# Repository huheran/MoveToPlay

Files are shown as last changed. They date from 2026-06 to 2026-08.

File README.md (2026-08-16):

<p align="center">
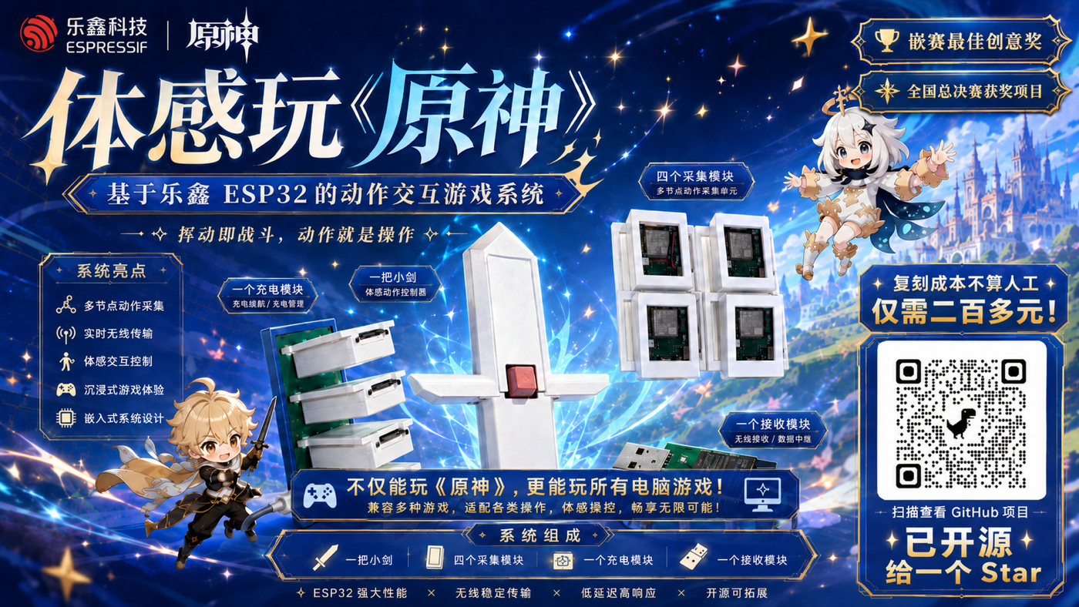
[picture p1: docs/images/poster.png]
MoveToPlay
  
</p>

# MoveToPlay

> 把身体变成手柄。

[English](README.en.md) · 简体中文


[]()
[]()
[]()

MoveToPlay 是一套基于 ESP32-S3 的开源体感外设。你在胸口、两只手、腿上各绑一个 Tracker，手里拿一把剑形的 Blade，插在电脑上的 Dongle 就能看懂你在跳、在挥剑、在奔跑，然后替你按下对应的按键。不用碰键盘和手柄，用身体直接打游戏。

## 目录

- [它能干什么](#它能干什么)
- [三个设备](#三个设备)
- [怎么玩](#怎么玩)
- [硬件](#硬件)
- [固件](#固件)
- [Windows Companion](#windows-companion)
- [训练自己的动作](#训练自己的动作)
- [云端训练服务](#云端训练服务)
- [目录结构](#目录结构)
- [许可证](#许可证)

## 它能干什么

对着屏幕挥一下剑，游戏里的角色就砍一刀；原地跳一下，角色就跳起来；迈步走路，角色就开始走。识别到的动作会变成真实的键盘、鼠标输入，所以理论上任何 PC 游戏都能用，只要把动作映射到对应的键。

默认键位是照着《原神》调的，开箱就能玩：

| 动作 | 默认输出 |
| --- | --- |
| 空闲 / 动作噪声 | 无 |
| 行走 | 按住 W |
| 奔跑 | 按住 Shift + W |
| 右手挥砍 | 鼠标左键连点 |
| 跳跃 | 空格 |
| 踢 | E |
| 左手抬起 | M |
| 右手抬起 | X |
| 双手交叉额头 | 角色键 1–4 循环 |
| 下压 | F |
| 射击 | 鼠标右键定时按住 |
| 左转 / 右转 | 视角左转 / 右转 |
| 奥特曼光线 | Q |

这套映射不是写死在固件里的。Dongle 有个 Wi-Fi 配置页，连上之后每个动作都能单独调输出、触发方式和阈值，改完保存在设备上，具体见[固件](#固件)。

## 三个设备

整套系统就三种硬件，各司其职：

- **Tracker × 4** —— 绑在胸口、右手、左手、腿上。里面是一颗 LSM6DSV 六轴 IMU，以 100 Hz 采样，通过 ESP-NOW 无线发给 Dongle。
- **Blade** —— 剑形控制器，一颗按键加一块 MAX30102 心率传感器。按住按键转动身体，胸口 Tracker 的陀螺仪就把转身和俯仰转成鼠标视角；采集数据时，这按键用来给动作打点。
- **Dongle** —— 插在电脑上的接收器。汇总所有节点的数据，在设备上跑随机森林识别动作，再伪装成 USB 键盘 + 鼠标输出。同时也是 USB 虚拟串口，供 Companion 读遥测、采数据、烧固件。

识别分两个随机森林：一个负责「持续状态」（空闲 / 走路 / 跑步 / 挥剑 / 动作噪声），50 棵树、5 个类别；另一个负责「瞬间动作」（跳、踢、抬手这些），180 棵树、15 个类别。特征都是 812 维，全部在 ESP32-S3 上本地跑，不依赖电脑端做任何识别。

## 怎么玩

最快的一条路：

1. **做硬件**。按下面的推荐组合打样 PCB、打印外壳、焊接。图纸在 `hardware/`。
2. **烧固件**。装好 ESP-IDF，把 6 个设备——1 个 Dongle、1 个 Blade、4 个 Tracker——依次编译烧录。
3. **绑上就玩**。Dongle 插电脑，Tracker 绑身上，开游戏。

只用官方公开的数据和模型的话，不用碰任何训练脚本。想用自己的动作重新训练，才需要 Python 和训练那套东西。

## 硬件

PCB 源工程和 3D 模型都在 `hardware/` 下，PCB 用的是嘉立创 EDA（`.eprj2`），外壳提供 SolidWorks / STEP / STL 三种格式。首次复刻推荐功能够用、结构最简单的 V1.0 组合：

- **Blade**：`Blade_V1.0_Nromal`（不带心率，文件名里的 `Nromal` 是早期拼写，保留原样）
- **Tracker**：手焊选 `Tracker_V1.0_Top-Battery`，贴片选 `Tracker_V1.0_Top-Battery_SMT`
- **Dongle**：`Dongle_SW1` / `Dongle_SW2` / `Dongle_SW3` 任选一个，只有按键不一样
- 充电底座，可选

这套组合不需要 `Blade_V2.0_HR(Heart Rate)` 和 `Heart_Rate_V2.0`。PCB 和外壳要按版本对应：V1.0 PCB 配 V1.0 模型，V2.0 配 V2.0，别混用。具体的工程清单、版本差异和对应关系见 [`hardware/pcb/README.md`](hardware/pcb/README.md) 和 [`hardware/3d-models/README.md`](hardware/3d-models/README.md)。

大文件走 Git LFS，克隆完先拉一下：

```bash
git lfs install
git lfs pull
```

投板前记得自己在嘉立创 EDA 里核对一遍 Gerber、钻孔、BOM、坐标和原理图，打印外壳前也核对尺寸和公差。

## 固件

固件工程在仓库根目录，ESP-IDF 5.5.x 就能编译：

```bash
idf.py build
idf.py -p <串口> flash monitor
```

三种设备共用同一份代码，靠 `main/app_main.c` 顶部的 `M2P_BOARD_PROFILE` 区分。改一次数字、烧一次：

| 值 | 设备 |
| --- | --- |
| `1` | Dongle |
| `2` | Blade |
| `3` | 胸口 Tracker |
| `4` | 右手 Tracker |
| `5` | 左手 Tracker |
| `6` | 腿部 Tracker |

```c
#define M2P_BOARD_PROFILE 1
```

推荐组合一共要烧 6 个设备，就是把上面这个数字从 1 到 6 各烧一遍。默认按 8 MB flash 构建（16 MB 的 Dongle 也能用），要显式指定的话：

```bash
# 8MB
idf.py -B build-tracker8mb \
  -D "SDKCONFIG=build-tracker8mb/sdkconfig" \
  -D "SDKCONFIG_DEFAULTS=sdkconfig.defaults.8mb" \
  build

# 16MB
idf.py -B build-dongle16mb \
  -D "SDKCONFIG=build-dongle16mb/sdkconfig" \
  -D "SDKCONFIG_DEFAULTS=sdkconfig.defaults.16mb" \
  build
```

Dongle 上长按按键 2 秒，会在三种运行状态之间循环，靠 LED 颜色区分：**绿 = 游戏**、**橙 = 采集**、**蓝 = Wi-Fi 维护**。进了蓝色状态后，手机或电脑连上 `MoveToPlay-Dongle` 这个热点（无密码），打开 `http://192.168.4.1/` 就能看设备状态、改动作映射。

配置页里每个动作可以设成：按一下键盘、按住键盘、角色键 1–4 循环、鼠标左键点击、鼠标右键定时按住、鼠标左键按住、鼠标左移 / 右移、视角左转 / 右转。触发方式有四种：冷却、刚出现、持续帧、重复。还能单独调每个动作的置信度阈值（30–95%）和冷却时间，配置存在设备 NVS 里，断电不丢。

## Windows Companion

Companion 是可选的 Windows 桌面端，面向买成品的人；自己复刻、只想体验体感控制的话可以不用装。它干这些事：

- 一个透明置顶、鼠标穿透的游戏悬浮层，显示当前动作、强度、心率、卡路里和连击
- 8 套主题：原神、鸣潮、我的世界、艾尔登法环、GTA V、赛博朋克 2077、通用、科幻竞技
- 动作事件标记、采集会话管理、上传训练、固件下载与回滚

需要 .NET 8 SDK 和 Windows 10/11：

```powershell
dotnet run --project companion/MoveToPlay.Companion/MoveToPlay.Companion.csproj
```

没有硬件时加 `--demo` 用模拟数据预览界面：

```powershell
dotnet run --project companion/MoveToPlay.Companion/MoveToPlay.Companion.csproj -- --demo
```

它会自动找 USB VID `303A`、PID `4005` 的 Dongle，设备插拔后自动重连。运行中 Dongle 每 100 ms 发一行 JSON 遥测——当前动作、置信度、强度、四个 Tracker 的在线和电量——Companion 拿来做悬浮层和统计。

点「结束运动并测量心率」会唤醒 Blade，用 MAX30102 测 10 秒心率；卡路里按动作 MET、强度和体重（默认 68 kg，`--weight` 可改）估算，不是医疗级数据。目前 Companion 只能烧 Dongle 固件，Blade 和 Tracker 还是得用 ESP-IDF 自己编译烧录。更多细节见 [`companion/MoveToPlay.Companion/README.md`](companion/MoveToPlay.Companion/README.md)。

## 训练自己的动作

想用自己的动作数据重新训练模型，流程是：采集 → 合并 → 训练 → 装进固件。用官方公开数据的话，跳过前两步，直接训练。

先准备环境。本地训练要 Python 3.11+，Windows 上一键搞定（第一次会建 `.venv-training` 并装好固定版本依赖）：

```powershell
# 先验证数据和环境
powershell -ExecutionPolicy Bypass -File training/run-local.ps1 -ValidateOnly -Reinstall
# 再训练
powershell -ExecutionPolicy Bypass -File training/run-local.ps1
```

也可以用 Docker，结果一致：

```powershell
docker build -f training/Dockerfile -t movetoplay-training:1 .
docker run --rm `
  --mount "type=bind,src=$PWD/data,dst=/workspace/data,readonly" `
  --mount "type=bind,src=$PWD/output,dst=/workspace/output" `
  movetoplay-training:1
```

每次训练都会生成一个独立目录，不会直接覆盖固件里的模型。训练通过质量门禁后，把产物装进固件、重新编译 Dongle：

```powershell
python tools/install_rf_model.py --run-dir output/training-runs/<run-id> --dry-run
python tools/install_rf_model.py --run-dir output/training-runs/<run-id>
idf.py -B build-dongle \
  -D "SDKCONFIG=build-dongle/sdkconfig" \
  -D "SDKCONFIG_DEFAULTS=sdkconfig.defaults.8mb" \
  build
```

**采集自己的数据**：用 Companion 采集，或者命令行：

```powershell
python -m pip install -r training/requirements-collection.txt
python tools/collect_imu_events.py --port COM6 --baud 115200 --output data/my-sessions/session_001.csv --autostart
```

**合并并生成 manifest**：

```powershell
python tools/prepare_rf_dataset.py --input-dir data/my-sessions --output-dir data/processed/my-dataset --dataset-id my-dataset
```

**训练自己的数据集**：

```powershell
powershell -ExecutionPolicy Bypass -File training/run-local.ps1 -DatasetManifest data/processed/my-dataset/dataset_manifest.json
```

数据格式很简单：samples 一行是 `pc_timestamp_ms,board_timestamp_ms,node_id,ax,ay,az,gx,gy,gz,state_label,session_id`，events 一行是 `event_id,event_group,event_type,pc_timestamp_ms,state_label,session_id`。`node_id` 固定 1=胸、2=右手、3=左手、4=腿，四个节点都得有数据。

公开数据由 Git LFS 管理，manifest 记录了大小、行数、标签分布和 SHA-256，训练前会逐项校验。两个模型都得过质量门禁才算通过：状态模型准确率 ≥ 0.98，事件模型准确率 ≥ 0.97、macro-F1 ≥ 0.96。还有个关键点：复现已部署模型必须用 `requirements.txt` 里固定的 scikit-learn 1.7.2，换个版本即使准确率一样，生成的数组内部结构也可能不同。完整的采集、合并、验证、Docker 复现和格式说明都在 [`training/README.md`](training/README.md)。

## 云端训练服务

不是复刻的必需步骤。`server/` 是一个 API + worker 分离的云端训练服务，共享 SQLite 状态库，负责数据校验、异步训练、质量门禁、固件编译和版本管理。API 只绑定 `127.0.0.1:8000`，走 SSH 隧道，业务接口要 Bearer Token。

人一多任务会排队，网络不稳也容易失败，所以现阶段建议本地训练。本地起一个做开发测试：

```powershell
python -m pip install -r server/requirements-dev.txt
Push-Location server
python -m pytest
Pop-Location
```

接口说明见 [`server/API_PROTOCOL.md`](server/API_PROTOCOL.md)，部署说明见 [`server/README.md`](server/README.md)。真实令牌、私钥、OSS 凭据都只放在服务器上，不要进 Git。

## 目录结构

```text
MoveToPlay/
├── main/             # ESP-IDF 固件（三种设备共用，generated/ 放模型 C 数组）
├── companion/        # Windows WPF 桌面端 + 冒烟测试
├── training/         # 训练流水线、Docker 环境和公开数据 manifest
├── data/             # Git LFS 管理的公开随机森林训练数据
├── server/           # 云端训练 API 与 worker
├── installer/        # Windows 安装包构建脚本（仅内部分发用）
├── hardware/
│   ├── pcb/          # 嘉立创 EDA PCB 源工程
│   └── 3d-models/    # SolidWorks / STEP / STL 结构模型
├── tools/            # 采集、分析、训练、导出脚本
├── analysis/         # 动作数据诊断脚本
├── partitions*.csv   # ESP32-S3 分区表
└── sdkconfig.defaults*   # ESP-IDF 默认配置
```

## 许可证

分目录授权：

- 软件、固件、训练工具、服务端和文档：Apache License 2.0（[`LICENSE`](LICENSE)、[`NOTICE`](NOTICE)）
- PCB 设计：CERN Open Hardware Licence v2 – Permissive（[`hardware/pcb/LICENSE`](hardware/pcb/LICENSE)）
- 3D 模型：CC0 1.0（[`hardware/3d-models/LICENSE`](hardware/3d-models/LICENSE)）
- 公开训练数据：CC0 1.0（[`data/LICENSE`](data/LICENSE)）

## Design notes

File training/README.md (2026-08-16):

# MoveToPlay 随机森林训练指南

本目录提供从 IMU 采集数据到 Dongle 固件随机森林 C 数组的完整可复现流水线。当前正式模型由两个随机森林组成：

- `state_rf_15_full`：识别 idle、walk、run、move_noise、right_hand_slash 等持续状态。
- `event_rf`：识别 jump、kick、抬手、转向等离散动作事件。

模型参数和质量门禁统一定义在 [`pipeline.json`](pipeline.json)。CNN 试验脚本不属于本指南，也不是当前固件的标准训练流程。

## 1. 环境要求

- Windows 10/11 与 PowerShell，或支持 Docker 的系统。
- Python 3.11 及以上版本。
- 采集真实硬件数据时需要 MoveToPlay Dongle 和四个 Tracker。
- 重新编译 Dongle 固件时需要 ESP-IDF 5.5.x。

克隆仓库后先下载 Git LFS 管理的数据和 PCB 工程：

```powershell
git lfs install
git lfs pull
```

## 2. 使用公开数据训练

仓库公开两套数据快照，说明见 [`../data/README.md`](../data/README.md)：

- `movetoplay-latest-v2`：默认数据集，用于新实验。
- `movetoplay-deployed-v1`：当前固件已部署模型使用的数据快照。

### Windows 一键验证

第一次运行会创建 `.venv-training` 并安装固定版本依赖：

```powershell
powershell -ExecutionPolicy Bypass -File training/run-local.ps1 -ValidateOnly -Reinstall
```

验证会检查 CSV 表头、文件大小、SHA-256、行数、会话数、四节点覆盖、标签分布、数值完整性和事件 ID 唯一性。

### Windows 一键训练

```powershell
powershell -ExecutionPolicy Bypass -File training/run-local.ps1
```

### 精确复现当前已部署模型

```powershell
powershell -ExecutionPolicy Bypass -File training/run-local.ps1 `
  -DatasetManifest training/datasets/movetoplay-deployed-v1.json `
  -RequireReferenceMatch
```

`-RequireReferenceMatch` 会要求新生成的 C 数组与仓库当前已部署数组一致，适合发布前审计。

精确复现必须使用 `training/requirements.txt` 固定的 scikit-learn 1.7.2。请通过 `run-local.ps1` 创建的 `.venv-training` 运行，不要直接使用安装了其他 scikit-learn 版本的系统 Python；即使准确率相同，不同版本也可能生成内部结构不同的随机森林数组。

## 3. 采集自己的动作数据

### 方法 A：使用 Windows Companion

运行桌面端：

```powershell
dotnet run --project companion/MoveToPlay.Companion/MoveToPlay.Companion.csproj
```

在 Dongle 上长按按钮约 2 秒切换到橙色数据采集模式，然后进入 Companion 的“数据采集与云端训练”页面。选择动作、开始会话并使用 Blade 或界面标记事件。每次会话会保存 samples CSV 和 events CSV。

### 方法 B：使用命令行采集

安装采集依赖：

```powershell
python -m pip install -r training/requirements-collection.txt
```

查看串口号后开始采集：

```powershell
python tools/collect_imu_events.py `
  --port COM6 `
  --baud 115200 `
  --output data/my-sessions/session_001.csv `
  --autostart
```

工具会同时生成 `session_001.csv` 和 `session_001_events.csv`。运行时会打印状态标签和事件标记快捷键；采集过程中应保证四个 Tracker 都在线。

建议每个动作采集多个人、多次会话，并保留 idle、walk、run 和 move_noise 等负样本。训练/测试划分按 `session_id` 分组，避免同一会话同时进入训练集和测试集造成数据泄漏。

## 4. 合并会话并生成 manifest

将准备训练的会话放入一个独立目录，然后运行：

```powershell
python tools/prepare_rf_dataset.py `
  --input-dir data/my-sessions `
  --output-dir data/processed/my-dataset `
  --dataset-id my-dataset
```

该命令会递归查找 samples/events CSV，输出：

```text
data/processed/my-dataset/
├── samples.csv
├── events.csv
└── dataset_manifest.json
```

如果已经自行合并好两份 CSV，也可以只生成 manifest：

```powershell
python tools/build_dataset_manifest.py `
  --samples data/processed/my-dataset/samples.csv `
  --events data/processed/my-dataset/events.csv `
  --dataset-id my-dataset `
  --output data/processed/my-dataset/dataset_manifest.json
```

manifest 会记录输入路径、字节数、SHA-256、行数、节点和标签分布。数据发生任何变化后都必须重新生成 manifest，不能手工沿用旧哈希。

## 5. 训练自己的数据集

先验证：

```powershell
powershell -ExecutionPolicy Bypass -File training/run-local.ps1 `
  -DatasetManifest data/processed/my-dataset/dataset_manifest.json `
  -ValidateOnly
```

验证通过后训练：

```powershell
powershell -ExecutionPolicy Bypass -File training/run-local.ps1 `
  -DatasetManifest data/processed/my-dataset/dataset_manifest.json
```

默认 `pipeline.json` 要求公开基线中的全部状态和事件类别。如果自定义数据只包含部分动作，需要同时调整 `required_classes` 和相关训练参数；不要为了通过门禁而简单降低指标，应先检查采集数量、标签时序和类别平衡。

## 6. 训练输出

每次执行都会创建独立目录，不会直接覆盖固件：

```text
output/training-runs/<run-id>/
├── dataset_validation.json
├── run_manifest.json
├── logs/
├── models/
│   ├── state_rf_15_full/
│   └── event_rf/
├── generated/
└── quality/
```

`run_manifest.json` 记录 Git 提交、工作区状态、Python 与依赖版本、数据/配置哈希、模型指标、质量门禁和所有产物哈希。只有两个模型都通过 `pipeline.json` 中的门禁，运行状态才会是 `passed`。

## 7. 将模型安装到 Dongle 固件

先使用 dry-run 检查训练产物：

```powershell
python tools/install_rf_model.py `
  --run-dir output/training-runs/<run-id> `
  --dry-run
```

确认后安装四个 C/H 数组：

```powershell
python tools/install_rf_model.py `
  --run-dir output/training-runs/<run-id>
```

脚本会把状态模型和事件模型复制到 `main/generated/`。随后重新编译 Dongle 固件：

```powershell
idf.py -B build-dongle `
  -D "SDKCONFIG=build-dongle/sdkconfig" `
  -D "SDKCONFIG_DEFAULTS=sdkconfig.defaults.8mb" `
  build
```

正式使用前应在未参与训练的新会话上验证误触发、漏识别和实时性能，并先保留上一版可回滚固件。

## 8. Docker 复现

在仓库根目录构建镜像：

```powershell
docker build -f training/Dockerfile -t movetoplay-training:1 .
```

使用公开默认数据训练：

```powershell
docker run --rm `
  --mount "type=bind,src=$PWD/data,dst=/workspace/data,readonly" `
  --mount "type=bind,src=$PWD/output,dst=/workspace/output" `
  movetoplay-training:1
```

训练数据不会被打包进 Docker 镜像，必须在运行时只读挂载；输出目录单独可写挂载。

## 9. 数据格式

samples CSV 必需列：

```text
pc_timestamp_ms,board_timestamp_ms,node_id,ax,ay,az,gx,gy,gz,state_label,session_id
```

events CSV 必需列：

```text
event_id,event_group,event_type,pc_timestamp_ms,state_label,session_id
```

`node_id` 固定为 `1=胸部`、`2=右手`、`3=左手`、`4=腿部`。新采集事件推荐使用全局唯一 `event_id`；历史数据允许在 `session_id` 范围内唯一。

## 10. 许可证

- 训练代码、脚本和文档使用 Apache License 2.0。
- `data/README.md` 明确列出的公开数据使用 CC0 1.0 Universal。

许可证详情见仓库根目录 [`LICENSE`](../LICENSE) 和数据目录 [`../data/LICENSE`](../data/LICENSE)。

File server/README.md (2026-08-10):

# MoveToPlay 云端训练服务

当前版本已经把玩家所选历史会话、官方基础数据合并、processed CSV 上传、完整性校验、异步训练、质量门禁、模型确认和产物下载串成一个闭环。API 与训练 worker 是两个独立容器，共享 SQLite 状态库和持久目录；worker 同一时间只执行一个任务，避免 8 GB ECS 被多个随机森林任务同时耗尽内存。

任务现在会按“准备数据、校验、状态模型训练/评估/导出、事件模型训练/评估/导出、质量门禁、云端固件编译与打包”汇报进度。每次训练通过后，worker 使用固定 SHA-256 的乐鑫官方 ESP-IDF 5.5.2 源码和 ESP32-S3 工具链，把 C 数组集成进 Dongle 固件，输出带 SHA-256 清单的完整烧录包。已批准任务组成模型版本库，可让云端重新编译固件或由电脑端下载烧录回滚；模型支持独立的可读名称，同时保留不可变的技术版本号，官方完整数据训练出的首个批准模型会标记为“官方基线”。配置 `MOVETOPLAY_OSS_*` 与 `OSS_ACCESS_KEY_*` 后，批准动作会异步把完整模型目录压缩备份到私有 OSS Bucket。

## 安全边界

- API 只绑定服务器回环地址 `127.0.0.1:8000`，当前通过 SSH 隧道访问，不开放公网端口。
- 除 `/`、`/health` 和接口文档外，业务接口都要求 Bearer Token。
- API 与 worker 均以 UID 1000 的非 root 用户运行，并启用 `no-new-privileges`。
- API 不挂载 Docker Socket，不能创建或控制其他容器。
- 上传文件最大 256 MiB，单个请求块最大 8 MiB；服务端校验声明大小、SHA-256 和 CSV 表头。
- 数据、任务状态、模型和 C 数组均保存在服务器持久目录，不进入 Git 或容器镜像。
- 持久目录权限为 `0700`，数据库和上传文件按 `0600` 创建。
- 训练通过质量门禁后仍不会自动更新固件，必须先调用人工审批接口。
- Python 基础镜像固定摘要；依赖固定版本并通过阿里云 PyPI 镜像下载。

完整接口和状态说明见 [API_PROTOCOL.md](API_PROTOCOL.md)。

## 本机测试

worker 测试会真正执行一次小型数据集校验，因此使用已安装训练依赖的隔离环境：

```powershell
.\.venv-training\Scripts\python.exe -m pip install -r server\requirements-dev.txt
Push-Location server
..\.venv-training\Scripts\python.exe -m pytest
Pop-Location
```

## 服务器配置

真实令牌只存于服务器：

```text
/home/movetoplay/MoveToPlay/shared/server.env
```

格式参考 `server.env.example`，文件权限应为 `0600`。部署时 Compose 会自动读取它。

`MOVETOPLAY_OFFICIAL_DATASET_ID` 必须指向已处于 `ready` 状态的官方完整数据集。客户端不会用玩家上一次训练结果替代它，确保官方数据不变、玩家只选择本次要加入的本地会话。

## 启动与检查

版本包由本机 `git archive` 生成并校验 SHA-256，再通过 SSH 上传。服务器运行：

```bash
/home/movetoplay/deploy-release.sh \
  /home/movetoplay/MoveToPlay/MoveToPlay-<提交ID>.tar.gz \
  <提交ID>

cd /home/movetoplay/MoveToPlay/current/server
docker compose ps
docker compose logs --tail 100 api worker
curl --fail --silent http://127.0.0.1:8000/health
```

## 从 Windows 上传

先保持 SSH 隧道窗口运行：

```powershell
ssh -L 8000:127.0.0.1:8000 movetoplay-server
```

在另一个 PowerShell 中设置令牌并上传。历史合并数据的 `event_id` 只在 session 内唯一，所以使用 `session`；新采集数据默认应使用全局唯一 ID。

`POST /api/v1/datasets` 可选传入 `base_dataset_id`。新数据仍按原大小和 SHA-256 续传，训练 worker 会递归展开已就绪的基础数据集链，在 Job 目录中合并 CSV，并给 `session_id`/`event_id` 添加来源数据集前缀。这样玩家只上传新动作会话，也能保留基础模型的全部旧动作。

```powershell
$env:MOVETOPLAY_API_TOKEN = '<服务器令牌>'
python tools\upload_training_dataset.py `
  --samples data\processed\event_samples_combined_slash_full.csv `
  --events data\processed\event_events_combined_slash_full.csv `
  --name 'movetoplay-latest-v2' `
  --event-id-scope session `
  --mode train `
  --wait
```

命令意外中断后，使用第一次输出的 dataset ID 加 `--dataset-id <ID>` 即可从服务器记录的字节偏移继续上传。

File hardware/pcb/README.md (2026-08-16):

# MoveToPlay PCB 复刻说明

本目录存放 MoveToPlay 各硬件模块的嘉立创 EDA 可编辑源工程和 PCB 预览图。每个 PCB 使用独立文件夹存放，文件夹名称同时表示模块、硬件版本及布局类型。

> 文件名中的 `Nromal` 和 `Botton` 是早期工程沿用的名称，含义分别为 `Normal`（标准版）和 `Bottom`（下置电池版）。为避免工程引用失效，仓库保留原文件名。

## 推荐复刻组合

如果只想体验 MoveToPlay 的体感控制和游玩原神，推荐先制作以下版本：

- `Blade_V1.0_Nromal`：不带心率检测，功能已经足够。
- Tracker V1.0：手工焊接选择 `Tracker_V1.0_Top-Battery`，使用 SMT 贴片生产选择 `Tracker_V1.0_Top-Battery_SMT`。
- `Dongle_SW1`、`Dongle_SW2` 或 `Dongle_SW3`：三者仅按键不同，任选一个即可。
- `充电底座`：需要集中充电时再制作。

采用这套基础组合时，不需要制作 `Blade_V2.0_HR(Heart Rate)` 和 `Heart_Rate_V2.0`。

## PCB 工程列表

| PCB 工程 | 用途与区别 |
| --- | --- |
| `Blade_V1.0_Nromal/Blade_V1.0_Nromal.eprj2` | Blade V1.0 标准版，不带心率传感器，推荐基础复刻使用 |
| `Blade_V2.0_HR(Heart Rate)/Blade_V2.0_HR(Heart Rate).eprj2` | Blade V2.0 心率版，增加心率传感器相关接口 |
| `Heart_Rate_V2.0/Heart_Rate_V2.0.eprj2` | Blade V2.0 使用的独立 MAX30102 心率传感器板 |
| `Tracker_V1.0_Top-Battery/Tracker_V1.0_Top-Battery.eprj2` | Tracker V1.0 上置电池版，为方便手工焊接而设计的器件布局 |
| `Tracker_V1.0_Top-Battery_SMT/Tracker_V1.0_SMT_Top-Battery.eprj2` | Tracker V1.0 上置电池 SMT 版，器件经过标准化，方便贴片生产 |
| `Tracker_V2.0_Botton-Battery/Tracker_V2.0_Botton-Battery.eprj2` | Tracker V2.0 下置电池版，为方便手工焊接而设计的器件布局 |
| `Tracker_V2.0_Botton-Battery_SMT/Tracker_V2.0_SMT_Botton-Battery.eprj2` | Tracker V2.0 下置电池 SMT 版，器件经过标准化，方便贴片生产 |
| `Dongle_SW1/Dongle_SW1.eprj2` | USB Dongle 第一种按键版本 |
| `Dongle_SW2/Dongle_SW2.eprj2` | USB Dongle 第二种按键版本 |
| `Dongle_SW3/Dongle_SW3.eprj2` | USB Dongle 第三种按键版本 |
| `充电底座/充电底座.eprj2` | Tracker 集中充电底座 |

## Blade V1.0 与 V2.0

Blade V2.0 在 V1.0 的基础上增加了心率传感器功能。心率检测不是体感控制原神所必需的功能，因此只体验游戏控制时使用 Blade V1.0 即可。

为了让心率传感器能够从 Blade 外壳开孔中露出，传感器被单独放在 `Heart_Rate_V2.0` PCB 上，并通过堆叠安装提高传感器位置。只有制作 Blade V2.0 心率版时才需要该 PCB；选择 Blade V1.0 时可忽略整个 `Heart_Rate_V2.0` 文件夹。

## Tracker V1.0 与 V2.0

Tracker V1.0 与 V2.0 的区别主要是 LED 发光方向和电池安装位置：

- V1.0 为 `Top-Battery`（电池上置）版本。
- V2.0 为 `Botton-Battery`（电池下置）版本。

两种版本的结构尺寸和安装位置不同，必须搭配相同版本的 3D 模型：V1.0 PCB 对应 V1.0 模型，V2.0 PCB 对应 V2.0 模型，不建议跨版本混装。

每个 Tracker 版本又提供两种 PCB 布局：

- 不带 `_SMT` 后缀：为方便手工焊接而调整的布局，适合个人复刻和调试。
- 带 `_SMT` 后缀：器件经过标准化，便于 SMT 贴片生产。

同一版本的手焊版和 SMT 版功能相同，并使用同一版本的 3D 外壳。选择哪一种只取决于焊接与生产方式。

## Dongle SW1、SW2 与 SW3

三个 Dongle 工程仅使用的按键不同，其他电路和功能没有区别。复刻时可以根据手头已有的按键或个人偏好任选一个版本。

## PCB 与 3D 模型对应关系

| PCB | 对应 3D 模型目录 |
| --- | --- |
| `Blade_V1.0_Nromal` | `../3d-models/solidworks建模/Blade剑身V1.0/`，并搭配 `Blade剑柄/` 和 `Blade上盖/` |
| `Blade_V2.0_HR(Heart Rate)` + `Heart_Rate_V2.0` | `../3d-models/solidworks建模/Blade剑身V2.0（心率检测）/`，并搭配 `Blade剑柄/` 和 `Blade上盖/` |
| `Tracker_V1.0_Top-Battery` 或 `Tracker_V1.0_Top-Battery_SMT` | `../3d-models/solidworks建模/Tracker上半面V1.0/` + `Tracker下半面V1.0/` |
| `Tracker_V2.0_Botton-Battery` 或 `Tracker_V2.0_Botton-Battery_SMT` | `../3d-models/solidworks建模/Tracker上半面V2.0（电池下置亚克力版本）/` + `Tracker下半面V2.0（电池下置亚克力版）/` |
| `充电底座` | `../3d-models/solidworks建模/充电底座/` |

更详细的模型文件说明请参阅 [`../3d-models/README.md`](../3d-models/README.md)。

## 打开与生产

`.eprj2` 是嘉立创 EDA 可编辑工程。克隆仓库后如果文件内容不完整，请先获取 Git LFS 文件：

```bash
git lfs install
git lfs pull
```

仓库中的 PNG 可用于快速查看 PCB 正反面或布局，但不能代替生产文件。正式投板前，请在嘉立创 EDA 中重新检查原理图、板层、板厚、铜厚、封装和设计规则，并导出及核对 Gerber、钻孔文件、BOM、贴片坐标和原理图 PDF。建议先少量打样并完成通电测试，再进行批量生产。

## 许可证

本目录中的 PCB 原理图、布局、嘉立创 EDA 工程和相关硬件设计资料使用 CERN Open Hardware Licence Version 2 - Permissive 发布。允许使用、研究、修改、分享设计以及制造和销售基于这些设计的产品，具体条件见 [`LICENSE`](LICENSE)。

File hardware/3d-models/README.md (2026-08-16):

# MoveToPlay 3D 模型复刻说明

本目录存放 MoveToPlay 外壳与结构件的 SolidWorks 源文件及通用交换格式。模型已经按照硬件模块和版本分类，复刻时请根据所选 PCB 版本进入对应文件夹。

## 文件格式

每个结构件通常提供三种格式：

- `.SLDPRT`：SolidWorks 可编辑源文件，适合修改结构设计。
- `.STEP`：通用 CAD 交换格式，适合导入其他建模软件、检查装配和继续编辑。
- `.STL`：三角网格模型，适合直接导入切片软件进行 3D 打印。

如果只需要打印外壳，通常下载 STL 即可；如果需要修改尺寸或适配其他元件，建议使用 SLDPRT 或 STEP。

## 模型目录

| 模型目录 | 用途 | 对应 PCB |
| --- | --- | --- |
| `solidworks建模/Blade剑身V1.0/` | 不带心率检测开孔的 Blade V1.0 剑身 | `../pcb/Blade_V1.0_Nromal/` |
| `solidworks建模/Blade剑身V2.0（心率检测）/` | 带心率检测结构的 Blade V2.0 剑身 | `../pcb/Blade_V2.0_HR(Heart Rate)/` + `../pcb/Heart_Rate_V2.0/` |
| `solidworks建模/Blade剑柄/` | Blade 剑柄结构件 | Blade V1.0 或 V2.0 |
| `solidworks建模/Blade上盖/` | Blade 上盖结构件 | Blade V1.0 或 V2.0 |
| `solidworks建模/Tracker上半面V1.0/` | Tracker V1.0 外壳上半部分 | 两种 Tracker V1.0 PCB |
| `solidworks建模/Tracker下半面V1.0/` | Tracker V1.0 外壳下半部分 | 两种 Tracker V1.0 PCB |
| `solidworks建模/Tracker上半面V2.0（电池下置亚克力版本）/` | Tracker V2.0 电池下置外壳上半部分 | 两种 Tracker V2.0 PCB |
| `solidworks建模/Tracker下半面V2.0（电池下置亚克力版）/` | Tracker V2.0 电池下置外壳下半部分 | 两种 Tracker V2.0 PCB |
| `solidworks建模/充电底座/` | Tracker 充电底座外壳 | `../pcb/充电底座/` |

## Blade 版本选择

- Blade V1.0 不带心率传感器。只体验 MoveToPlay 的体感控制和游玩原神时，建议选择该版本。
- Blade V2.0 带心率检测结构，需要同时制作 `Blade_V2.0_HR(Heart Rate)` 主 PCB 和独立的 `Heart_Rate_V2.0` 心率传感器 PCB。
- 心率传感器采用独立 PCB 堆叠安装，使传感器能够升高并从外壳开孔中露出。

Blade V1.0 PCB 必须搭配 `Blade剑身V1.0`，Blade V2.0 PCB 必须搭配 `Blade剑身V2.0（心率检测）`。剑柄和上盖为两种版本都会使用的结构件。

## Tracker 版本选择

Tracker 的 PCB 与外壳按版本一一对应：

- Tracker V1.0 PCB 对应 `Tracker上半面V1.0` 和 `Tracker下半面V1.0`。
- Tracker V2.0 PCB 对应 `Tracker上半面V2.0（电池下置亚克力版本）` 和 `Tracker下半面V2.0（电池下置亚克力版）`。

V1.0 与 V2.0 的 LED 发光方向、电池位置和外壳结构不同，请勿将 V1.0 PCB 与 V2.0 外壳混用，反之亦然。

每个 Tracker 版本均有手焊布局和 SMT 标准化布局。是否带 `_SMT` 后缀不会改变 3D 模型的版本：同为 V1.0 就使用 V1.0 外壳，同为 V2.0 就使用 V2.0 外壳。

## 制作建议

1. 先确定 Blade 和 Tracker 的 PCB 版本，再下载相同版本的模型。
2. 打印前在切片软件中检查模型单位和实际尺寸，确认模型未被自动缩放。
3. 根据打印机、材料和装配松紧度设置合理公差；首次制作建议先打印关键连接位置进行试装。
4. 安装前检查按键、LED、USB 接口、心率传感器和充电触点的开孔方向。
5. V2.0 Tracker 使用亚克力结构时，请根据实际板材厚度和加工公差检查装配。

## 许可证

本目录中的 3D 模型使用 CC0 1.0 Universal 发布，可以复制、修改、分发和使用，包括商业用途，无需事先申请许可或署名。详情见本目录的 [`LICENSE`](LICENSE)。

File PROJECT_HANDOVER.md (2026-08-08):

# MoveToPlay 工程交接总结

MoveToPlay 是一套基于 ESP32-S3 的多人穿戴式体感控制系统：四个 Tracker 采集身体 IMU 数据，Blade 提供实体按键状态，Dongle 汇总所有无线数据，在本地完成动作识别和逻辑后处理，最终模拟 USB 键盘和鼠标控制电脑游戏。

目前它已经是完整的业务原型，不再是 README 所描述的“ESP-IDF 基础模板”。

## 1. 当前仓库状态

- 分支：`main`
- 远程仓库：`https://github.com/huheran/MoveToPlay.git`
- 最新提交：`def112b`，2026-07-18
- 工程历史：78 个提交，主要开发者为 `hhr` 和 `Rowlexting`
- ESP-IDF：5.5.2
- 芯片：ESP32-S3
- 默认 Flash：8 MB
- 当前工作区存在一处未提交修改：

```c
#define M2P_BOARD_PROFILE 2
```

也就是当前源码被切换成了 Blade 固件。提交版本原本是 `1`，即 Dongle。

本次检查没有修改源码，只重跑了构建。当前 Blade 配置构建成功：

- 固件大小：772,944 字节
- App 分区：7 MB
- 分区剩余约 89%
- 统一 Dongle 与 Blade Profile 均已在 ESP-IDF 5.5.2 下零警告构建
- 全部 Python 脚本通过语法检查
- 尚未进行实机通信、USB HID 和动作识别验证

最重要的编译入口位于 `main/app_main.c`。

---

## 2. 整体架构

```mermaid
flowchart LR
    T["4 个 Tracker<br/>胸部、右手、左手、腿部"] -->|"ESP-NOW / IMU 100 Hz"| D["ESP32-S3 Dongle"]
    B["Blade<br/>实体按键与电量"] -->|"ESP-NOW"| D
    D --> E["15 类事件 RF<br/>25 帧窗口"]
    D --> S["5 类状态 RF<br/>15 帧窗口"]
    E --> P["置信度、平滑、冷却、状态恢复"]
    S --> P
    B --> P
    P --> H["USB HID<br/>键盘 + 鼠标"]
    H --> PC["电脑游戏"]
    Phone["手机或电脑浏览器"] -->|"Wi-Fi AP / HTTP"| D
```

系统包含六种可烧录角色：

| Profile | 角色 | 节点 ID | 用途 |
|---:|---|---:|---|
| 1 | Dongle | — | 接收、识别、USB HID 输出 |
| 2 | Blade | 100 | 实体按键、视角控制使能、休眠 |
| 3 | Chest Tracker | 1 | 胸部 IMU |
| 4 | Right Hand Tracker | 2 | 右手 IMU |
| 5 | Left Hand Tracker | 3 | 左手 IMU |
| 6 | Leg Tracker | 4 | 腿部 IMU |

所有角色共用同一个 `main/app_main.c`，通过宏裁剪出不同固件。

---

## 3. 各设备职责

### Tracker

每个 Tracker：

- 通过 SPI 读取 LSM6DSV 六轴 IMU。
- IMU 配置为约 120 Hz ODR，任务按 100 Hz 读取。
- 读取加速度 `ax/ay/az`，单位 g。
- 读取陀螺仪 `gx/gy/gz`，单位 dps。
- 每个有效样本通过 ESP-NOW 广播给 Dongle。
- 每 5 秒读取一次电池电压并附带到数据包。
- SK6812 灯显示电量，并每 2 秒短暂熄灭一次作为心跳。
- IMU 初始化失败时快速闪灯三次并循环。

IMU 驱动见 `main/imu_lsm6dsv.c`。

### Blade

Blade 当前只有按键和电量，没有使用 IMU：

- GPIO4，低电平按下。
- 50 Hz 消抖轮询。
- 松开时按 5 Hz 发送心跳。
- 按下时按 25 Hz 上报。
- 状态变化时连续发送三次，减少无线丢包影响。
- 按住 Blade 时，Dongle 使用胸部 Tracker 的陀螺仪控制水平和垂直视角。
- Blade 本身目前不直接输出鼠标点击。

休眠手势：

1. 连续短按四次；
2. 每次间隔不超过 700 ms；
3. 第五次按住 5 秒；
4. 进入深度睡眠。

唤醒后还需要继续按住 3 秒确认，否则重新休眠。

### Dongle

Dongle 完成系统的大部分业务逻辑：

- 接收 Tracker 和 Blade 的 ESP-NOW 数据。
- 保存各节点最新状态、电量、时间和序号。
- 每 40 ms，即 25 Hz，构造一次四节点识别帧。
- 运行事件模型和状态模型。
- 做置信度门限、连续帧确认、动作冷却和状态恢复。
- 输出 USB 键盘与鼠标报告。
- 提供 Wi-Fi 状态与动作配置页面。
- 将动作配置持久化到 NVS。

---

## 4. 硬件引脚

板型定义位于 `main/move_to_play_board_config.h`。

### 旧版 Tracker 板

| 功能 | GPIO |
|---|---:|
| SPI SCLK | 12 |
| SPI MOSI | 11 |
| SPI MISO | 9 |
| SPI CS | 10 |
| SK6812 | 38 |
| 电池 ADC | GPIO4 / ADC1_CH3 |

### 新版 Tracker 板

| 功能 | GPIO |
|---|---:|
| SPI SCLK | 13 |
| SPI MOSI | 12 |
| SPI MISO | 11 |
| SPI CS | 14 |
| SK6812 | 38 |
| 电池 ADC | GPIO2 / ADC1_CH1 |

当前四个 Tracker 的 `BOARD_STYLE` 都设为 `1`，即新版板。

Blade 和 Dongle 会复用 Chest 的板型配置，因此当前：

- Blade 按键：GPIO4
- Blade 电池：GPIO2
- Dongle Wi-Fi 维护模式按钮：GPIO4
- 状态灯：GPIO38

---

## 5. ESP-NOW 通信协议

协议定义见 `main/m2p_espnow.h`。

关键参数：

- 固定 Wi-Fi 信道：6
- 发射功率：10 dBm
- 广播地址：`FF:FF:FF:FF:FF:FF`
- 不加密、不配对
- 接收队列长度：16
- 协议当前版本：2
- 最低兼容版本：1
- 单包约 44 字节

包内容包括：

- Magic：`M2PN`
- 协议版本
- 包类型
- 节点 ID
- 标志位
- 发送序号
- 设备时间戳
- 六轴 IMU
- 电池电压
- 电池百分比

包类型：

- `TRACKER_IMU`
- `BLADE_STATE`

版本 2 在版本 1 的 40 字节基础上增加电池字段，代码保持了向后兼容。

需要注意：

- 没有设备身份认证。
- 没有应用层校验和。
- 没有序号去重或乱序处理。
- 广播数据可被同信道上的其他设备接收或伪造。
- 队列满时新包会被静默丢弃。

---

## 6. 动作识别

### 输入结构

模型要求四个 Tracker 全部在线：

1. Chest
2. Right Hand
3. Left Hand
4. Leg

任一节点未收到数据或最后数据超过 250 ms，当前帧不推理。

每个节点使用八个通道：

- `ax, ay, az`
- `gx, gy, gz`
- 加速度模长
- 陀螺仪模长

### 特征工程

模型共使用 812 个特征：

- 单节点统计：4 × 8 × 10 = 320
- 六组节点对差值统计：6 × 8 × 10 = 480
- 节点对模长相关系数：6 × 2 = 12

合计 812。

每个通道的十个统计特征包括：

- 均值
- 标准差
- 最大值
- 最小值
- 极差
- RMS
- 能量
- Jerk 平均绝对值
- Jerk 标准差
- Jerk RMS

### 双模型融合

#### 事件模型

- 窗口：25 帧，约 1 秒
- 随机森林：180 棵树
- 节点总数：61,776
- 类别数：15

类别：

```text
hands_cross_forehead
hands_press_down
hands_shoot
idle
jump
kick
left_hand_raise
move_noise
right_hand_raise
right_hand_slash
run
turn_left
turn_right
ultraman_beam
walk
```

#### 状态模型

- 窗口：15 帧，约 600 ms
- 随机森林：50 棵树
- 节点总数：11,744
- 类别数：5

类别：

```text
idle
move_noise
right_hand_slash
run
walk
```

融合规则：

1. 如果事件模型识别到非状态动作，优先采用事件模型。
2. 否则采用状态模型。
3. 如果状态模型无效，再退回事件模型结果。

固件实现见 `main/rf_infer.c` 和 `main/rf_state_infer.c`。

---

## 7. 识别后处理

Dongle 并不是识别出什么就立即发送什么，还加入了较多游戏控制规则：

- 默认置信度门限：60%
- 跳跃有效门限最多按 40% 处理
- 行走/奔跑有效门限最多按 52% 处理
- 普通动作连续确认三帧
- 新进入行走/奔跑需要连续四帧
- 左右转不经过普通平滑，减少视角延迟
- 左转后 800 ms 内阻止立即反向右转，反之亦然
- 事件动作发生后，可在 200 ms 内恢复先前行走/奔跑状态
- 事件与状态的桥接窗口为 320 ms
- Blade 松开后，最多保留移动按键 220 ms
- 移动中跳跃会发送 `W+Space` 或 `Shift+W+Space`，避免跳跃时丢失前进状态
- 支持冷却、边沿、持续帧和重复四种触发模式

这些逻辑主要集中在 `main/app_main.c`。

---

## 8. 默认动作映射

| ID | 动作 | 默认输出 | 触发方式 |
|---:|---|---|---|
| 0 | 双手交叉额头 | 依次循环数字键 1/2/3/4 | 新出现，800 ms |
| 1 | 双手下压 | F | 冷却 600 ms |
| 2 | 双手射击 | 鼠标右键按住 500 ms | 新出现 |
| 3 | 空闲 | 无 | — |
| 4 | 跳跃 | Space | 新出现，1000 ms |
| 5 | 踢 | E | 冷却 1000 ms |
| 6 | 左手抬起 | M | 新出现，800 ms |
| 7 | 动作噪声 | 无 | — |
| 8 | 右手抬起 | X | 新出现，800 ms |
| 9 | 右手挥砍 | 鼠标左键点击 | 每 500 ms 重复 |
| 10 | 奔跑 | Shift+W 按住 | 状态保持 |
| 11 | 左转 | 鼠标左移 | 每 40 ms |
| 12 | 右转 | 鼠标右移 | 每 40 ms |
| 13 | 奥特曼光线 | Q | 冷却 1000 ms |
| 14 | 行走 | W 按住 | 状态保持 |

这些只是默认值。最终值可能已被写入 Dongle NVS，运行时会优先加载 NVS 配置。

---

## 9. Blade 视角控制

按住 Blade 且 Blade 数据不超过 300 ms 时：

- 胸部 `gy` 控制鼠标 X，即左右视角。
- 胸部 `gx` 控制鼠标 Y，即上下视角。
- 水平死区：8 dps
- 垂直死区：8 dps
- 水平灵敏度：10 像素/积分角度
- 垂直灵敏度：8
- 单次水平最大变化：80
- 单次垂直最大变化：64
- 胸部数据必须在 150 ms 内
- 约每 20 ms 输出一次鼠标报告

按住 Blade 时，该逻辑优先于模型识别出的左右转动作。

---

## 10. Dongle 的三种模式

Dongle 现在只有一份统一固件。每次长按 GPIO4 两秒按顺序切换：

| 运行状态 | 指示灯 | USB 数据 | 推理 | USB HID | 用途 |
|---|---|---|---|---|---|
| Play | 绿色 | 动作与设备状态 JSON | 开启 | 开启 | 正式游戏 |
| Data Collect | 橙色 | 四节点原始六轴 CSV | 关闭 | 关闭 | 采集训练数据 |
| Wi-Fi Maintenance | 蓝色 | 切换为 USB Serial/JTAG | 关闭 | 关闭 | 查看节点与修改配置 |

切换顺序为 `Play → Data Collect → Wi-Fi Maintenance → 重启回 Play`。进入采集态前固件会释放所有按住的键盘和鼠标报告；Play 与采集态共用同一个 TinyUSB CDC 端口，因此切换采集不需要重新枚举 USB，也不需要重新烧录。

采集态的 Tracker CSV 末尾包含 Dongle 接收时间。Blade 每次有效按下边沿会发送 `#M2P_EVENT,blade_click,<dongle_ms>,<sequence>`；固件等待一次松开后才允许下一次标记，因此状态变化突发重发不会制造重复事件。Companion 使用同一 Dongle 时钟对齐样本和事件，并提供即时补偿与倒计时提示音两种方式。

---

## 11. Wi-Fi 配置与维护模式

Dongle 在橙色采集态下再次长按 GPIO4 两秒进入 Wi-Fi 模式：

- SSID：`MoveToPlay-Dongle`
- 无密码
- 地址：`http://192.168.4.1/`
- 状态灯变蓝
- 暂停 RF 推理和 HID 输出
- USB 从 TinyUSB HID 切换为硬件 USB Serial/JTAG，便于维护和重新烧录
- Tracker 状态更新降频到每节点 200 ms

页面可查看：

- 八个 Tracker 槽位的在线状态
- Blade 在线和按键状态
- 电池百分比和电压
- 最后数据时间
- 序号和运行时间

可配置每个动作的：

- 输出类型
- 键盘键
- 修饰键
- 触发方式
- 置信度
- 冷却时间
- 持续帧数

配置按模型动作 ID 保存，而不是按类别序号保存。新模型的未知动作会自动出现在表格中并默认禁用输出；玩家配置后才会产生键鼠动作。旧版15类序号配置首次加载时会按原动作 ID 自动迁移，因此模型类别排序变化不会导致按键错配。

保存后写入 NVS：

- Namespace：`m2p_dongle`
- Key：`actions`
- 配置版本：2

再次长按 GPIO4 两秒会重启并回到绿色 Play 状态。

HTTP 接口：

```text
GET  /
GET  /api/status
GET  /api/config
POST /api/config
POST /api/config/reset
```

当前 AP 和配置接口均无认证，只适合封闭现场环境。

---

## 12. USB HID

USB 模块模拟一个组合设备：

- 厂商字符串：`MoveToPlay`
- 产品字符串：`MoveToPlay HID KM`
- 键盘 Report ID：1
- 鼠标 Report ID：2
- 轮询间隔：1 ms
- 单次发送等待上限：100 ms

代码位于 `main/usb_keyboard.c`。

USB 模式切换要特别注意：

- Play 状态下电脑看到 HID 键盘、鼠标和 CDC 串口。
- Data Collect 状态沿用相同 CDC 串口输出原始 CSV，不重新枚举 USB。
- 进入 Wi-Fi 维护模式后，TinyUSB 会被卸载，切换为 USB Serial/JTAG。
- 想退出维护模式需要再次长按两秒，由固件重启回 Play。
- 如果 Dongle 无法被正常识别，首先确认烧录的是 Profile 1 的统一 Dongle 固件。

---

## 13. 电量与 LED

电量计算当前较简单：

- 分压比固定为 2.0
- 4.2 V 映射为 100%
- 3.0 V 映射为 0%
- 中间线性插值
- 无多点校准
- 无滤波和滑动平均

Tracker LED：

- 75%以上：绿色
- 50%～75%：黄色
- 25%～50%：橙色
- 25%以下：红色
- 每两秒短暂熄灭一次表示仍在运行

这套计算更适合作为粗略状态提示，不能当成精确剩余容量。

---

## 14. 目录与模块说明

| 路径 | 职责 |
|---|---|
| `main/app_main.c` | 角色选择、任务启动、Dongle 全部业务逻辑 |
| `main/imu_lsm6dsv.*` | LSM6DSV SPI 驱动 |
| `main/m2p_espnow.*` | ESP-NOW、Wi-Fi 和协议 |
| `main/rf_infer.*` | 15 类事件模型推理 |
| `main/rf_state_infer.*` | 5 类状态模型推理 |
| `main/generated/` | 已部署的 RF C 数组 |
| `main/usb_keyboard.*` | TinyUSB 键盘和鼠标 |
| `main/battery_monitor.*` | ADC 电池采样 |
| `main/status_led.*` | RMT 驱动 SK6812 |
| `tools/collect_imu_data.py` | 旧版状态标签数据采集 |
| `tools/collect_imu_events.py` | 当前事件/状态联合采集 |
| `tools/train_event_rf.py` | 当前 RF 训练入口 |
| `tools/export_rf_model_c.py` | joblib 模型导出为固件 C 数组 |
| `tools/retrain_models.sh` | 当前两个部署模型的训练命令备份 |
| `tools/rf_baseline.py` | 早期 RF 基线 |
| `tools/cnn1d_train.py` | CNN 训练实验 |
| `tools/imu_*` | 串口监控、姿态融合、动作可视化 |
| `analysis/` | 跳跃误识别诊断脚本 |

值得注意：CNN 相关源文件虽然还在，但没有被 `main/CMakeLists.txt` 编译。当前正式固件只使用两个随机森林。

---

## 15. 构建和烧录

推荐使用 ESP-IDF 5.5.2 PowerShell 环境。普通 PowerShell 没有自动设置 `IDF_PATH`，直接构建会失败。

标准流程：

```powershell
# 先在 main/app_main.c 中修改 M2P_BOARD_PROFILE，再使用 VS Code ESP-IDF 按钮或以下命令

idf.py build
idf.py -p COMx flash monitor
```

独立 8 MB 构建：

```powershell
idf.py -B build-tracker8mb `
  -D "SDKCONFIG=build-tracker8mb/sdkconfig" `
  -D "SDKCONFIG_DEFAULTS=sdkconfig.defaults.8mb" build

idf.py -B build-tracker8mb -p COMx flash monitor
```

16 MB Dongle：

```powershell
idf.py -B build-dongle16mb `
  -D "SDKCONFIG=build-dongle16mb/sdkconfig" `
  -D "SDKCONFIG_DEFAULTS=sdkconfig.defaults.16mb" build
```

默认 8 MB 分区：

- NVS：24 KB
- PHY：4 KB
- Factory App：7 MB

16 MB 配置的 Factory App 为 15 MB。

目前没有 OTA 分区，所有升级都依赖有线烧录。

此外，工程名称仍是 `esp_idf_template`，所以输出文件也是：

```text
build/esp_idf_template.bin
```

这属于历史遗留命名。

---

## 16. 数据采集与模型训练

当前推荐链路：

1. 将 Dongle 设为 Profile 1。
2. 烧录统一 Dongle 固件；绿色 Play 下长按两秒，看到橙灯后进入采集态。
3. 四个 Tracker 全部上线。
4. 在 Companion 预选或新增事件动作，选择 Blade 即时标记或倒计时提示音后收集样本；`collect_imu_events.py` 保留为命令行诊断工具。
5. 按 40 ms 时间网格对齐四个节点。
6. 使用 `train_event_rf.py` 分别训练状态模型和事件模型。
7. 使用 `export_rf_model_c.py` 导出 C 数组。
8. 将批准后的 C 数组集成并重新编译统一 Dongle 固件。
9. 长按切回 Wi-Fi 后再长按重启至绿色 Play，用实机串口和 HID 行为验证。

云端数据集支持 `base_dataset_id`。Companion 默认以最后一次训练通过的数据集作为基础，只上传当前新会话；worker 在任务目录中按数据集链合并 CSV，并给 session/event ID 加来源前缀避免冲突。事件模型质量门禁要求原15类仍存在，同时允许新增类别，并对新增类别执行相同的召回率检查。

当前训练命令记录在 `tools/retrain_models.sh`。

训练流水线依赖：

```text
data/processed/event_samples_combined_slash_full.csv
data/processed/event_events_combined_slash_full.csv
```

这两个恢复后的文件目前位于工程中，并已在本机和云端完成完整流水线复核。

同时：

- `data/`
- `model/`
- `output/`
- `main/generated/`

都被 `.gitignore` 忽略，不过已被 Git 跟踪的 RF 生成文件仍会保留。

因此全新克隆仓库后：

- 可以拿现有生成数组编译固件；
- 不能完整复现当前模型训练；
- 训练原始数据、joblib、训练报告和混淆矩阵可能缺失。

当前本地 `model/rf_model_meta.json` 还是旧的十分类模型信息，与固件中的十五分类模型不一致，不应把它当成当前部署模型。

Python 依赖也没有 `requirements.txt`。从代码看至少涉及：

```text
pyserial
pynput
numpy
pandas
scikit-learn
joblib
matplotlib
seaborn
torch
```

---

## 17. 主要风险与技术债

### 高优先级

#### 1. 编译角色依靠手工修改源码

当前为了适配实际烧录习惯，仍在 `main/app_main.c` 中手工修改 `M2P_BOARD_PROFILE`，然后使用 VS Code ESP-IDF 按钮编译、烧录。烧录前必须再次核对编号，避免把 Blade、Tracker 或 Dongle 固件烧错；切换回常用板子后也应及时恢复该值。

如果未来改为自动化构建矩阵，应同时提供 VS Code 中清晰可见的板子选择入口，不能只把选择方式隐藏到 CMake 参数中。

#### 2. 缺少完整构建矩阵

C 预处理会裁掉其他角色代码。成功构建 Blade 不代表 Dongle、四个 Tracker 和三种 Dongle 模式都能编译。

至少应在 CI 中构建：

- Dongle View
- Dongle Collect
- Dongle Play
- Blade
- 四个 Tracker Profile

#### 3. 模型不可完整复现

当前训练数据、模型 bundle 和训练报告不在 Git 中，重训脚本引用的输入也缺失。

需要把数据放进明确的数据归档、对象存储或发布包，并记录数据版本和模型哈希。

#### 4. README 严重过时

README 开头仍声称这是基础 LED 模板，且包含无意义测试文本。下一任不能依赖现有 README 理解系统。

### 中优先级

#### 5. `app_main.c` 过于庞大

文件接近 3,900 行，混合了：

- 角色配置
- 无线接收
- 推理
- HID
- Web 页面
- NVS
- Blade 休眠
- 电量
- 任务管理

建议拆成 `dongle_runtime`、`action_mapper`、`web_config`、`blade_runtime`、`tracker_runtime` 等模块。

#### 6. 无自动化测试

当前没有：

- C 单元测试
- 协议编码/解码测试
- RF C/Python 一致性测试
- HID 状态机测试
- Web 配置测试
- CI 配置

#### 7. 无线和配置接口无安全保护

ESP-NOW 广播不加密，SoftAP 无密码，配置接口无认证。现场附近的其他设备理论上可以干扰或修改配置。

#### 8. USB、Wi-Fi 和 HID 耦合较强

进入 Wi-Fi 页面会暂停推理、释放按键并切换 USB 模式。这是有意设计，但接手者很容易误以为设备“停止识别”或“USB 消失”。

### 较低优先级

9. 电量模型粗糙，缺少滤波和板级校准。

10. Tracker 没有深度睡眠，只有 Blade 实现省电。

11. 无 OTA，仅有一个 Factory App 分区。

12. 协议时间戳为 32 位微秒，大约 71.6 分钟回绕。

13. ESP-NOW 接收队列满时静默丢包，缺少丢包计数和链路质量指标。

14. 依赖已有更新版本，但当前锁定版本可正常构建：

```text
esp_tinyusb 2.1.1，可更新到 2.2.1
tinyusb 0.19.0~2，可更新到 0.21.0~1
```

不建议接手第一天立即升级，应先建立硬件回归测试。

---

## 18. 建议下一任接手顺序

### 第一阶段：先保证可控

1. 确认当前未提交的 Blade Profile 修改是否需要保留并提交。
2. 分别给六种硬件建立明确的构建命令或脚本。
3. 更新 README，记录设备照片、串口号、MAC、安装位置和烧录版本。
4. 对现有成套硬件完成一次端到端测试。
5. 备份当前可以正常工作的固件二进制。

### 第二阶段：补齐可复现性

1. 找回 `data/processed` 中部署模型对应的数据。
2. 找回两个 RF 的 joblib、训练摘要和混淆矩阵。
3. 建立 `requirements.txt` 或 Conda 环境。
4. 给模型数据、生成数组和固件建立共同版本号。
5. 增加 Python 模型和 C 推理结果一致性测试。

### 第三阶段：再做重构

1. 拆分 `app_main.c`。
2. 用 Kconfig 或构建参数替代源码角色宏。
3. 增加 CI 构建矩阵。
4. 加入协议统计、丢包率和节点版本信息。
5. 评估 ESP-NOW 加密、AP 密码和配置认证。
6. 评估 OTA 和双分区升级。

## 一句话交接结论

目前系统的核心闭环已经完整跑通：四节点体感采集、无线汇聚、双随机森林识别、Blade 辅助控制、USB 键鼠输出和网页配置都已经实现。最大的接手风险不是某一个算法，而是“角色靠手改宏、主文件过大、模型训练资产不完整、缺少全角色自动化验证”。接手者应先固化构建与数据版本，再继续优化识别效果或扩展功能。

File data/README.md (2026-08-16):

# MoveToPlay 随机森林训练数据

本目录公开 MoveToPlay 双随机森林流水线使用的规范化 CSV 数据。大文件由 Git LFS 管理，克隆仓库后请先运行：

```bash
git lfs install
git lfs pull
```

## 已公开数据集

### movetoplay-latest-v2

用于新实验的最新恢复数据，包含后续追加的采集会话：

- `processed/event_samples_combined_slash_full.csv`
- `processed/event_events_combined_slash_full.csv`
- manifest：[`../training/datasets/movetoplay-latest-v2.json`](../training/datasets/movetoplay-latest-v2.json)

### movetoplay-deployed-v1

用于复现当前固件中已部署随机森林数组的数据快照：

- `processed/event_samples_combined_slash_full.csv.pre_zhq10_zhq11_20260808_140431.bak`
- `processed/event_events_combined_slash_full.csv.pre_zhq10_zhq11_20260808_140431.bak`
- manifest：[`../training/datasets/movetoplay-deployed-v1.json`](../training/datasets/movetoplay-deployed-v1.json)

manifest 记录文件路径、字节数、SHA-256、行数、会话数、节点编号和标签分布。训练开始前，流水线会逐项验证，防止数据损坏或误用其他版本。

## CSV 格式

samples CSV 至少包含：

```text
pc_timestamp_ms,board_timestamp_ms,node_id,ax,ay,az,gx,gy,gz,state_label,session_id
```

events CSV 至少包含：

```text
event_id,event_group,event_type,pc_timestamp_ms,state_label,session_id
```

`node_id` 必须覆盖四个 Tracker：

| node_id | 佩戴位置 |
| --- | --- |
| `1` | 胸部 |
| `2` | 右手 |
| `3` | 左手 |
| `4` | 腿部 |

## 使用自己的数据

请勿直接修改上述官方快照。使用 Companion 或 `tools/collect_imu_events.py` 创建新的会话目录，然后运行：

```powershell
python tools/prepare_rf_dataset.py `
  --input-dir data/my-sessions `
  --output-dir data/processed/my-dataset `
  --dataset-id my-dataset
```

该工具会合并 samples/events CSV，并自动生成与训练流水线兼容的 `dataset_manifest.json`。完整步骤见 [`../training/README.md`](../training/README.md)。

## 许可证

本目录中明确纳入 Git 的训练数据使用 CC0 1.0 Universal 发布，可以复制、修改、重新训练、分发和用于商业目的，无需申请许可或署名。详情见 [`LICENSE`](LICENSE)。

未纳入 Git 的本地个人会话、临时备份和恢复文件不属于公开数据发布内容。

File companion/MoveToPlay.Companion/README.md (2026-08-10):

# MoveToPlay Companion Prototype 01

这是 MoveToPlay 的 Windows 桌面端运动伴侣。当前版本默认通过 Dongle 的 USB CDC 复合接口接收真实动作数据，同时保留显式模拟模式用于没有硬件时预览界面。

主窗口的“数据采集与云端训练”入口还可以读取 Dongle 运行时采集态的原始六轴数据、维护可编辑动作事件库、预选本次动作，并用 Blade 单击完成即时或倒计时标记。Tracker 与 Blade 使用统一 Dongle 接收时间对齐，即时方式支持延迟补偿；事件库保存在“文档/MoveToPlay/event_catalog.json”。“我的采集数据”按会话列出全部本地历史记录，玩家可任意勾选合并、定向删除自己的会话；每次提交训练都必须先经过该页。所选玩家会话只叠加到服务器固定的只读官方数据集，官方数据不会被删改或重复累积。统一 Dongle 固件每次长按按钮 2 秒按“绿色 Play → 橙色采集 → 蓝色 Wi-Fi → 重启回绿色 Play”循环，不再为采集单独烧录固件。训练通过后，服务器会把模型 C 数组集成进 Dongle 工程并编译为完整固件包；玩家确认采用后，软件只下载和校验固件，再用内置烧录工具写入蓝灯维护模式的 Dongle，本机无需 ESP-IDF。队友安装包内置只能转发训练 API 的受限 SSH 身份，首次运行后使用 Windows DPAPI 加密保存凭据；开发构建在没有团队凭据时仍使用本机 `movetoplay-server` SSH 配置。云端 API 继续只监听服务器 `127.0.0.1:8000`。

游玩悬浮层把连接/强度状态与动作激励弹窗分开保存。Dongle 的事件计数增加时，软件锁定本次动作名称、主题激励语和连击数，弹窗播放结束前不会被后续高频 USB CDC 状态包覆盖；设备连接提示只保留在常驻状态区域。

- 透明置顶、鼠标点击穿透的游戏悬浮层；主窗口不再绘制模拟游戏预览，启用时直接覆盖目标游戏所在的整个显示器；
- 自动选择目标游戏所在显示器，并以整个屏幕作为悬浮层坐标范围；
- 切出游戏时自动隐藏；
- 悬浮层只绘制文字、状态点和目标进度线，不显示任何卡片底色或边框；
- 文字使用字形级黑色描边与零偏移柔和阴影，在明暗复杂的游戏画面上仍可辨认；
- 8 套配置化主题：原神、鸣潮、我的世界、艾尔登法环、GTA V、赛博朋克 2077、通用和科幻竞技；
- 每套主题可独立配置文字、标记符号、字体、进度线样式、悬浮位置和运动激励；
- 当前动作、心率、估算卡路里、运动时间和连击展示；
- 游戏化运动激励动画；
- `Ctrl + Shift + F10` 全局显示/隐藏快捷键。
- 点击主窗口右上角关闭按钮后隐藏到 Windows 系统托盘，动作接收和统计继续运行；双击托盘图标恢复，右键菜单可真正退出。
- 主界面只保留“打开悬浮层控制”入口；独立置顶控制窗打开时自动显示真实悬浮层，可边看游戏画面边调整九宫格锚点、水平/垂直偏移，并分别缩放主题标题、当前动作、运动统计、目标进度和激励提示。每个主题与分辨率的设置自动保存到 `%LOCALAPPDATA%\MoveToPlay\overlay-placements.json`。

## 运行

```powershell
dotnet run --project companion/MoveToPlay.Companion/MoveToPlay.Companion.csproj
```

或者构建后运行：

```powershell
dotnet build companion/MoveToPlay.Companion/MoveToPlay.Companion.csproj -c Release
companion/MoveToPlay.Companion/bin/Release/net8.0-windows/MoveToPlay.Companion.exe
```

软件默认自动查找 USB VID `303A`、PID `4005` 的 MoveToPlay Dongle，并在设备插拔后自动重连。也可以手动指定端口和用户体重：

```powershell
dotnet run --project companion/MoveToPlay.Companion/MoveToPlay.Companion.csproj -- --port=COM35 --weight=68
```

只有需要预览随机模拟数据时才使用：

```powershell
dotnet run --project companion/MoveToPlay.Companion/MoveToPlay.Companion.csproj -- --demo
```

## Dongle 遥测协议

源码开发环境的云端功能要求 `ssh movetoplay-server` 已经可以通过密钥登录；队友安装包不需要提前配置 SSH。可运行客户端冒烟测试：

```powershell
dotnet run --project companion/MoveToPlay.Companion.Smoke -c Release

# 验证本地采集会话的扫描、选择合并和定向删除
dotnet run --project companion/MoveToPlay.Companion.Smoke -c Release -- --collection-library

# 验证已下载云端固件包的清单、大小与 SHA-256（不烧录）
dotnet run --project companion/MoveToPlay.Companion.Smoke -c Release -- `
  --firmware-package JOB_ID firmware-bundle.zip

# 同时验证 C# 分块上传与云端 validate Worker
dotnet run --project companion/MoveToPlay.Companion.Smoke -c Release -- `
  data/zhq12.csv data/zhq12_events.csv
```

Dongle 在 Play 模式下枚举为 HID 键盘/鼠标与 CDC 虚拟串口复合设备。CDC 每 100 ms 发送一行 UTF-8 JSON，电脑端以换行符分包。当前协议版本为 1，内容包括：

- Dongle 序号与单调时间戳；
- 当前动作、识别置信度、运动强度和有效运动状态；
- 实际键鼠动作事件与累计事件数；
- 四个 Tracker 的在线掩码、在线数量和信号质量；界面每秒检查最新数据，串口长时间无数据时自动重连；
- Blade 在线状态及各设备电量。

电脑端根据动作 MET、运动强度、有效运动时间和用户体重估算卡路里。默认体重暂为 68 kg，可用 `--weight` 修改。识别置信度只表示模型对动作类别的确定程度，不作为运动强度使用。

云端训练页会显示具体训练阶段、进度、已用时间和预计剩余时间；训练期间不再混入上一次模型指标，完成后才展示准确率与质量门禁。训练通过后由服务器集成 C 数组、编译并打包完整 Dongle 固件，电脑端只下载和校验固件，再调用随软件提供的官方烧录工具。独立的“模型版本库”页支持让云端重新编译历史固件，以及选择蓝灯维护串口后一键回滚并烧录。电脑端无需安装 ESP-IDF。

## 当前边界

- 默认数据源是 `UsbCdcTelemetryService`；`DemoTelemetryService` 只在 `--demo` 模式启用。
- MAX30102 平时保持低功耗关闭；玩家点击“结束运动并测量心率”后，Companion 经 USB CDC 与 ESP-NOW 唤醒 Blade，检测手指后静止测量 10 秒，完成后自动关闭并生成本地运动报告。测量失败时会根据有效运动时间、动作强度与估算消耗给出明确标注为“非传感器实测”的估算心率，保证报告仍可生成。
- 当前卡路里是基于动作 MET、Dongle 运动强度、有效运动时间和体重的估算值，不用于医疗判断。
- WPF 置顶层适用于窗口化和无边框全屏。真正的独占全屏可能覆盖普通桌面窗口。
- 悬浮层不注入游戏进程，只创建独立透明窗口。

## 后续接入点

数据源统一实现 `Services/ITelemetrySource.cs`。真实串口由 `UsbCdcTelemetryService` 负责自动发现、解析和重连，模拟预览由 `DemoTelemetryService` 提供。

主题位于 `Profiles/*.json`，后续为不同游戏增加 JSON 配置即可。自动绑定支持精确进程名，也支持“进程名 + 窗口标题”组合规则，避免误认通用的 Unreal/Java 进程。

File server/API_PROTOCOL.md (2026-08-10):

# MoveToPlay 云端训练 API v1

基础地址为 `http://127.0.0.1:8000`。当前应通过 SSH 隧道使用；所有 `/api/v1/` 请求都带：

```http
Authorization: Bearer <token>
```

## 数据集流程

`GET /api/v1/system-config` 返回服务器固定的 `official_dataset_id`。Companion 每次只把玩家在“我的采集数据”中勾选的会话叠加到这个只读官方数据集，不会把上一次玩家训练结果继续作为基础数据，因而不会重复累计历史会话。

1. `POST /api/v1/datasets`：声明 samples/events 的文件名、字节数和 SHA-256，获得 dataset ID。
2. `PUT /api/v1/datasets/{id}/files/samples`：上传原始二进制块，并提供 `X-Upload-Offset`。
3. `PUT /api/v1/datasets/{id}/files/events`：同上。
4. `GET /api/v1/datasets/{id}`：查询两个文件各自已接收的字节数，用于断点续传。
5. `POST /api/v1/datasets/{id}/complete`：核对总长度、SHA-256 和必需 CSV 列；成功后状态变为 `ready`。

创建请求示例：

```json
{
  "name": "collection-2026-08-08",
  "samples": {
    "filename": "samples.csv",
    "bytes": 123456,
    "sha256": "64位十六进制SHA-256"
  },
  "events": {
    "filename": "events.csv",
    "bytes": 1234,
    "sha256": "64位十六进制SHA-256"
  },
  "event_id_scope": "global",
  "base_dataset_id": "可选的32位基础数据集ID"
}
```

上传是严格顺序追加的。若客户端偏移与服务器不一致，服务器返回 HTTP 409 和正确的 `expected_offset`；客户端应查询数据集后从该位置继续。完成后的数据集不可修改，哈希错误的数据集会标记为 `rejected`，需要重新创建。

`base_dataset_id` 省略或传 `null` 时是独立数据集；传入一个已处于 `ready` 状态的数据集后，worker 会递归合并基础链和本次 CSV。合并时会为 `session_id`、`event_id` 增加来源数据集前缀，避免不同采集会话发生 ID 冲突。

## 训练任务流程

- `POST /api/v1/jobs`：为 `ready` 数据集创建任务，`mode` 为 `validate` 或 `train`。
- `GET /api/v1/jobs`：列出任务。
- `GET /api/v1/jobs/{id}`：查询单个任务。
- `GET /api/v1/jobs/{id}/artifacts`：列出运行产物。
- `GET /api/v1/jobs/{id}/artifacts/{path}`：下载单个产物。
- `POST /api/v1/jobs/{id}/approve`：人工批准状态为 `passed` 的训练任务。
- `GET /api/v1/models`：列出全部已批准模型版本及名称、来源、当前采用、固件和 OSS 备份状态。
- `PATCH /api/v1/models/{id}`：修改模型的人类可读名称，请求体为 `{ "name": "评委演示模型" }`；传 `null` 恢复默认名称，技术版本号不变。
- `POST /api/v1/models/{id}/activate`：把已批准历史版本设为当前采用模型。

任务响应同时返回 `progress_stage`、`progress_detail`、`progress_percent`、
`elapsed_seconds` 和 `estimated_remaining_seconds`。训练未结束前客户端不展示旧模型指标；
完成后再读取 `run_manifest.json` 显示准确率与质量门禁。

任务状态变化：

```text
queued -> running -> validated   （仅校验）
                  -> passed      （训练和质量门禁通过）
                  -> failed
```

训练请求：

```json
{
  "dataset_id": "32位十六进制ID",
  "mode": "train"
}
```

审批请求：

```json
{
  "approved_by": "操作者名称"
}
```

`approved` 记录人工决策。训练通过后 worker 自动把已校验 C 数组集成进 Dongle 工程，在固定 ESP-IDF 环境中编译并生成 `firmware/firmware-bundle.zip`。Companion 只允许对 `passed` 且存在 `approved_at` 的任务下载并校验完整固件包，并在用户再次确认串口后调用内置烧录工具。
批准时服务器分配不可变的 `model_version`，将它设为当前版本，并在配置 OSS 后异步归档完整运行目录。

历史任务可通过 `POST /api/v1/jobs/{job_id}/firmware` 请求固件；请求体 `{ "force": true }` 会让云端重新编译。任务响应中的 `firmware_status`、`firmware_progress_percent`、`firmware_detail` 和 `firmware_error` 分别表示固件状态、进度、当前阶段和错误。

## 旧任务清理规则

- 已批准模型：本地永久保留，并自动备份到 OSS；不会被清理任务删除。
- 失败任务：默认保留 7 天。
- 仅校验任务：默认保留 14 天。
- 通过但未批准任务：默认保留 30 天。
- 排队中和运行中任务：永不清理。

保留天数均可通过 `MOVETOPLAY_CLEANUP_*_DAYS` 调整；可先运行
`python -m app.maintenance --dry-run` 预览清理范围。

## 持久目录

```text
/home/movetoplay/MoveToPlay/shared/
|-- server.env
|-- state/movetoplay.sqlite3
|-- datasets/<dataset-id>/samples.csv
|-- datasets/<dataset-id>/events.csv
|-- jobs/<job-id>/dataset_manifest.json
|-- jobs/<job-id>/pipeline.log
`-- artifacts/training-runs/<job-id>/
    `-- firmware/{firmware-manifest.json,firmware-bundle.zip,*.bin}
```

SQLite 使用 WAL 和 30 秒 busy timeout。API 负责写入上传与任务记录，单 worker 原子领取队列中最早的任务；worker 重启后会把中断的 `running` 任务重新放回队列。

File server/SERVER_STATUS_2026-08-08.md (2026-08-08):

# MoveToPlay ECS 状态记录（2026-08-08）

## 服务器与运行版本

- 阿里云 ECS：Ubuntu 24.04.4 LTS，4 vCPU，约 8 GB 内存，40 GB 系统盘。
- Docker 29.1.3；Docker Compose 2.40.3。
- 当前部署版本：Git 提交 `5939f2cc26aca75fb08ba45fb9e3bf021ca02acc`。
- 部署包 SHA-256：`90431bfab0b5ca5263aa8534fc147db03a939008915ef0bcb36b306ac3bce8f6`。
- `movetoplay-server`：FastAPI，状态 `healthy`，容器用户 `app`。
- `movetoplay-training-worker`：训练队列 worker，容器用户 `worker`。
- 两个容器都启用 `no-new-privileges:true`，UID 为 1000；API 没有挂载 Docker Socket。
- API 仅监听 `127.0.0.1:8000`，ECS 安全组没有开放业务端口。

## 已上线的训练闭环

- Bearer Token 鉴权；真实令牌仅存于服务器 `shared/server.env`，权限 `0600`。
- processed samples/events CSV 分块上传，单块最大 8 MiB，支持按字节偏移续传。
- 声明大小、SHA-256、CSV 必需列、四节点、事件/样本 session 关系和流水线数据校验。
- SQLite WAL 持久任务队列，API 与单 worker 分离。
- `validate` 和 `train` 两种任务，状态可查询。
- 双随机森林训练、质量门禁、joblib 模型和 C 数组生成。
- 运行产物列表与单文件下载。
- 训练通过后的人工审批记录；没有自动写入固件或下发设备。
- 持久目录权限 `0700`，数据库、数据和产物文件按 `0600` 创建。

接口协议见 `server/API_PROTOCOL.md`，参考上传客户端为 `tools/upload_training_dataset.py`。

## ECS 冒烟测试

- 数据集 ID：`1477c0342d064c1b8bbaf02c001777b8`
- 校验任务 ID：`856d870b2acb45a286711ba0a67bebed`
- 状态变化：`queued -> running -> validated`
- 产物通过鉴权 API 下载后与服务器文件逐字节一致。
- 运行清单记录 Python 3.13.9 和源提交 `5939f2cc26aca75fb08ba45fb9e3bf021ca02acc`。

## 完整历史数据云端训练

- 数据集 ID：`309794a8bc3e4a1b951321153260f3db`
- 训练任务 ID：`9968a258eb204188b18682471f30a4d8`
- 输入：1,218,686 条 samples，1,722 条 events。
- 时间：2026-08-08 18:55:31 至 19:16:55（北京时间），约 21 分 24 秒。
- 状态：`passed`，尚未人工审批。
- `state_rf_15_full`：accuracy `0.990346127`，macro F1 `0.990847717`，质量门禁通过。
- `event_rf`：accuracy `0.991435245`，macro F1 `0.988198508`，质量门禁通过。
- 四个生成的 `.c/.h` 文件与本机 `local-full-v1b` 的 SHA-256 全部一致，证明云端复现了本机结果。
- 训练峰值内存低于 3 GiB；任务结束后 API/worker 常驻内存约 41/46 MiB。
- 运行目录约 17 MiB；系统盘验收时使用率约 12%。

完整云端运行目录已备份到：

```text
D:\git_fork_sure_mine\MoveToPlay_backups\2026-08-08-server-deploy\cloud-training-run-9968a258eb204188b18682471f30a4d8.tar.gz
SHA-256: b012e0e5ed3a57ce52ca3dc4740962fc48a81b50cb444bebaaf2f8ee1d7cb1a4
```

上传使用的服务器临时中转副本已经删除；API 持久目录中的正式数据保留并重新核验了 SHA-256。

## 持久目录

```text
/home/movetoplay/MoveToPlay/shared/
|-- server.env
|-- state/movetoplay.sqlite3
|-- datasets/<dataset-id>/
|-- jobs/<job-id>/
`-- artifacts/training-runs/<job-id>/
```

## 日常检查

```bash
cd /home/movetoplay/MoveToPlay/current/server
docker compose ps
docker compose logs --tail 100 api worker
curl --fail --silent http://127.0.0.1:8000/health
```

## 下一步边界

服务器训练闭环已经可用。下一阶段是把分块上传客户端接入 Windows Companion 的“数据采集训练模式”，并选择公网接入方式。正式开放公网前必须配置域名、HTTPS、限流和令牌轮换；固件更新接口只能选择已经通过质量门禁且人工审批的任务。

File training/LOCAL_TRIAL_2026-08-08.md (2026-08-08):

# 本机训练流水线试验记录（2026-08-08）

## 环境

- Windows 11
- Python 3.13.9（隔离环境 `.venv-training`）
- scikit-learn 1.7.2
- numpy 2.3.5
- pandas 2.3.3
- scipy 1.16.3
- joblib 1.5.3
- 本机未安装 Docker；Dockerfile 已生成，实际验证使用与其相同的固定 Python 依赖。

## 数据版本发现

恢复的数据中存在两个有明确意义的版本：

1. `movetoplay-deployed-v1`
   - 当前固件模型实际使用的数据快照。
   - 1,177,590 条样本、1,665 条事件。
   - 对应加入 zhq10/zhq11 之前的 processed 备份。
2. `movetoplay-latest-v2`
   - 朋友最近提供的最终 processed 文件。
   - 1,218,686 条样本、1,722 条事件。
   - 比 deployed-v1 多 zhq10、zhq11 两个会话，尚未被当前固件模型使用。

历史数据的 `event_id` 仅在单个 session 内唯一；跨 session 有 385 个重名，
但 `(session_id, event_id)` 没有重复。未来服务器上传应生成全局唯一事件 ID。

## 最新数据训练试验

运行目录：`output/training-runs/local-full-v1b/`

- 总耗时约 6 分 53 秒。
- 状态模型：
  - accuracy：0.990346126677655
  - 50 棵树、11,186 个节点、812 个特征
  - 质量门禁通过
- 事件模型：
  - accuracy：0.991435245263431
  - 180 棵树、62,664 个节点、812 个特征
  - 质量门禁通过
- C 数组导出成功。
- 与当前固件数组不相同，符合预期，因为 latest-v2 增加了两个会话。

## 当前部署模型严格复现

运行目录：`output/training-runs/deployed-reproduction-v1/`

- 总耗时约 6 分 57 秒。
- 状态模型：
  - accuracy：0.993974507531866
  - 50 棵树、11,284 个节点、812 个特征
  - C 数组与当前固件内容一致
- 事件模型：
  - accuracy：0.991047919957873
  - 180 棵树、63,114 个节点、812 个特征
  - C 数组与当前固件内容一致
- 两个重新训练的 joblib 文件与恢复的历史 joblib 逐字节、SHA-256 完全一致：
  - state：`CD8B2577AE41AAA19C814B4080BB30276C2FF14BC34D4D89F63DEEF9DDFCB1E5`
  - event：`030DD25A94581801D51E6580D3DFD521EC3262864C26568258C1B95D29C13931`

这证明数据快照、依赖版本、随机种子、训练参数和导出流程已经完整恢复。

## 资源观察

- 特征构建阶段观察到约 2.9 GB 进程内存峰值。
- 云端训练容器最低建议 4 GB，实际建议至少 8 GB 内存。
- 当前随机森林训练不需要 GPU。

## 尚未包含的远程功能

- Companion 的数据采集界面和上传客户端。
- 服务器认证、分片/断点上传、对象存储和任务队列。
- 原始 session 到新 processed 数据集版本的显式构建器。
- Python 与固件 C 推理逐窗口预测一致性测试。

这些功能应建立在当前已经验证的训练入口之上，不应把网络上传逻辑混入模型训练脚本。

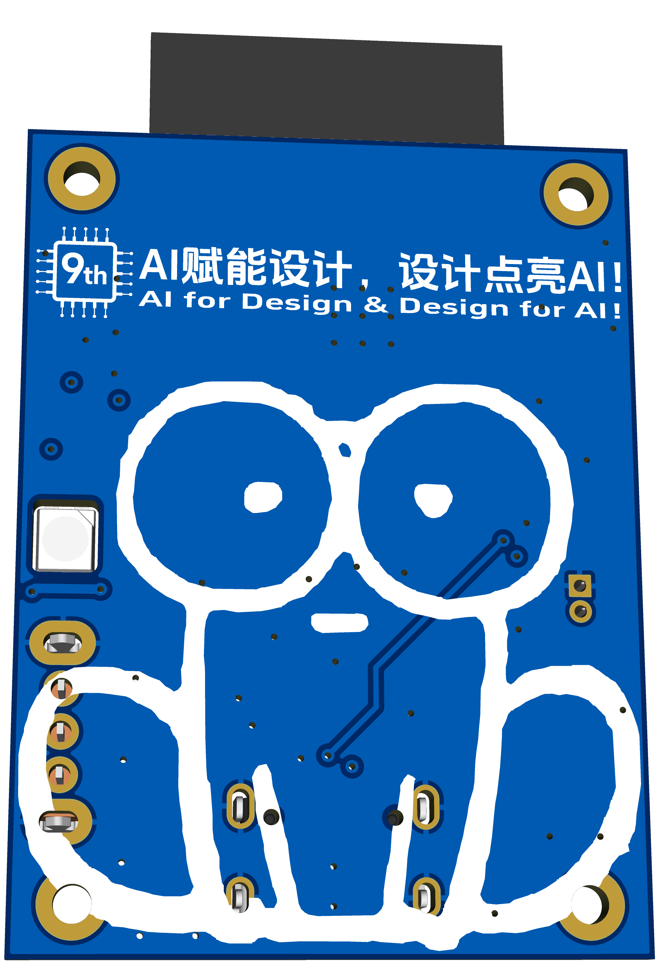
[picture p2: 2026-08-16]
hardware/pcb/Tracker_V1.0_Top-Battery_SMT/Tracker_V1.0_SMT_Top-Battery_.png

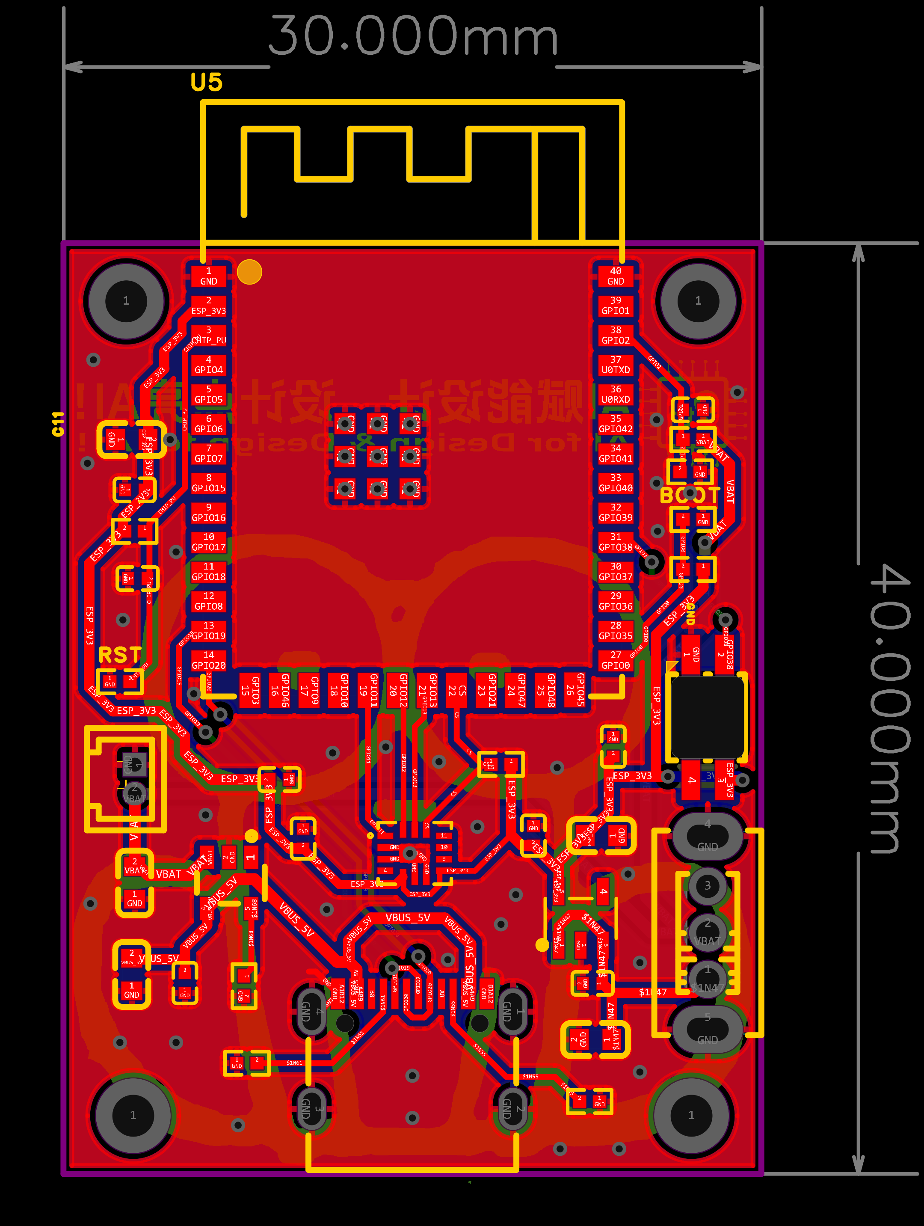
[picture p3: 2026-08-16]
hardware/pcb/Tracker_V1.0_Top-Battery_SMT/Tracker_V1.0_SMT_Top-Battery.png

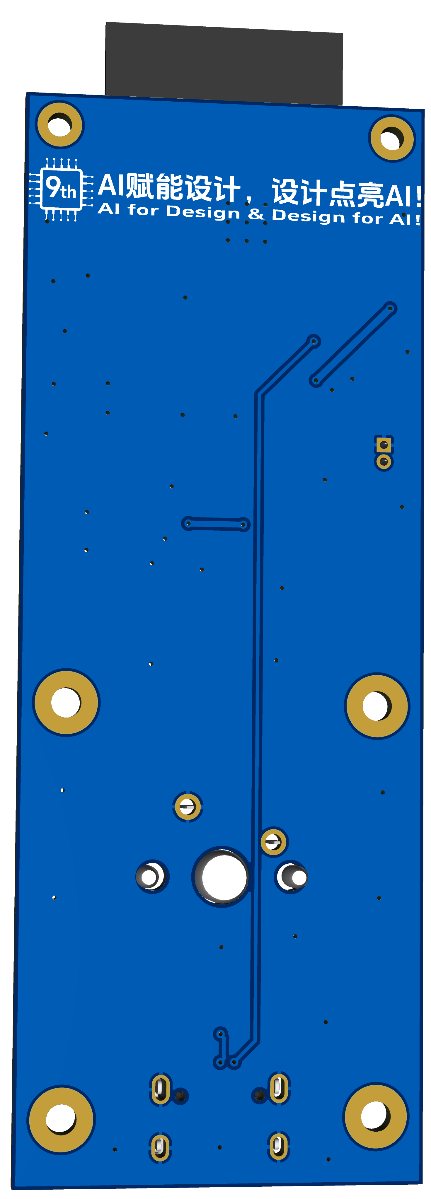
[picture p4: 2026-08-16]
hardware/pcb/Blade_V1.0_Nromal/Blade_V1.0_Nromal-.png

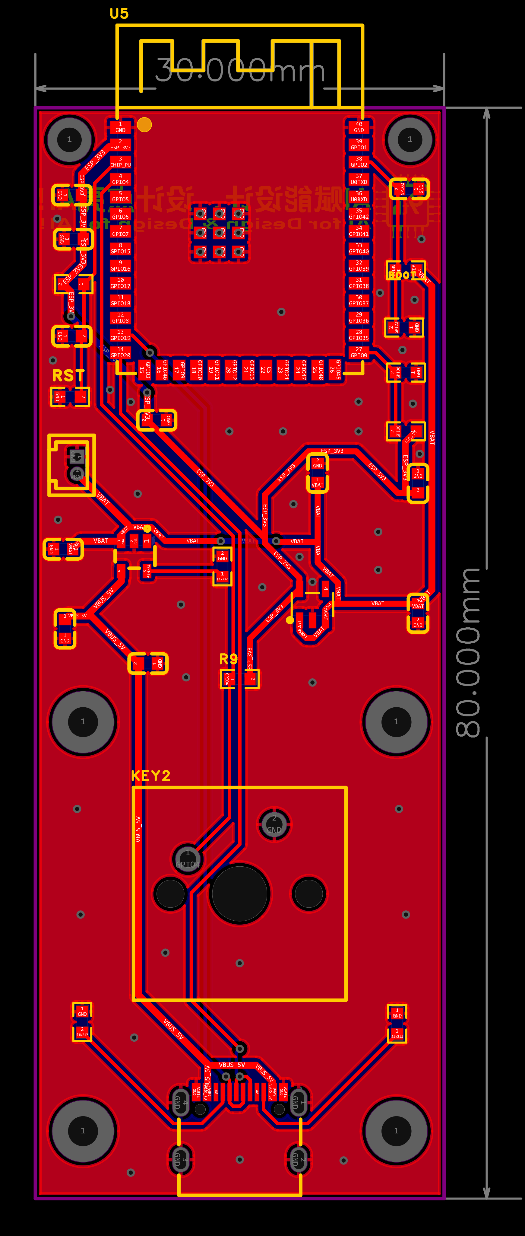
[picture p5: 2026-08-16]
hardware/pcb/Blade_V1.0_Nromal/Blade_V1.0_Nromal.png

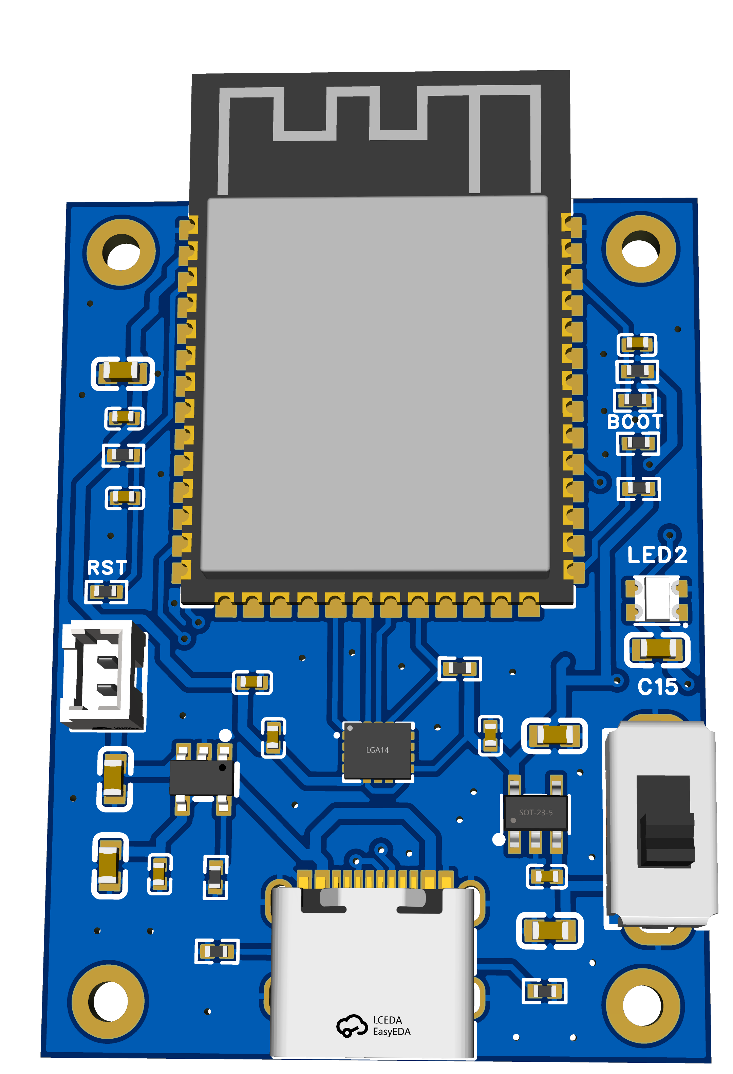
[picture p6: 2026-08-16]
hardware/pcb/Tracker_V2.0_Botton-Battery_SMT/Tracker_V2.0_SMT_Botton-Battery_.png

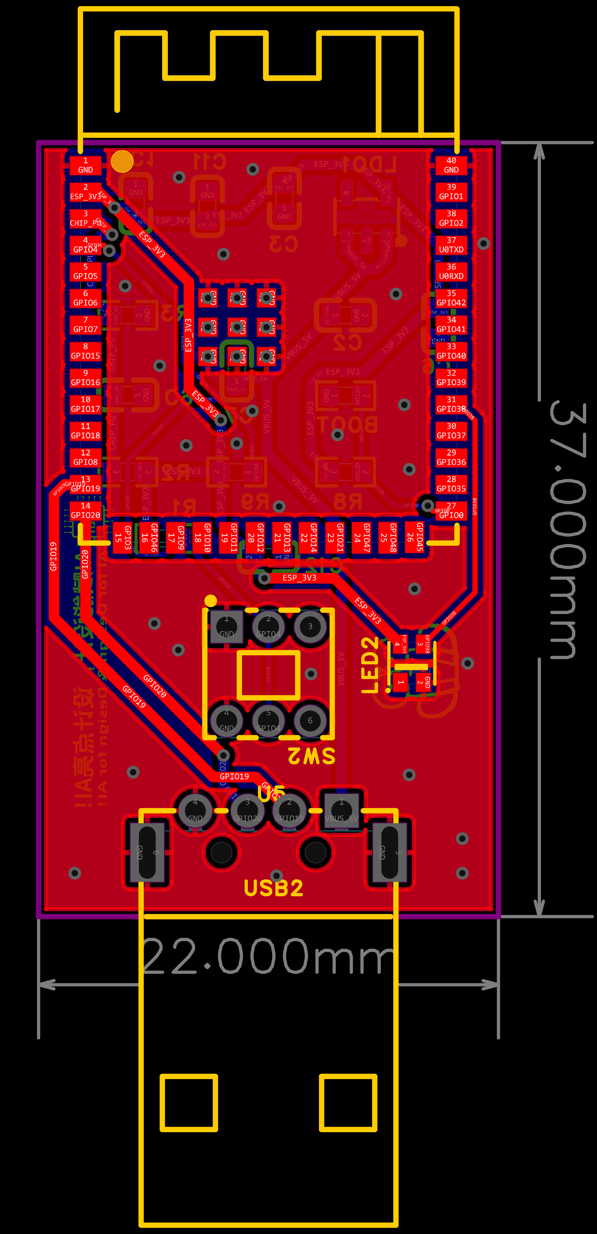
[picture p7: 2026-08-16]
hardware/pcb/Dongle_SW2/Dongle_SW2.png

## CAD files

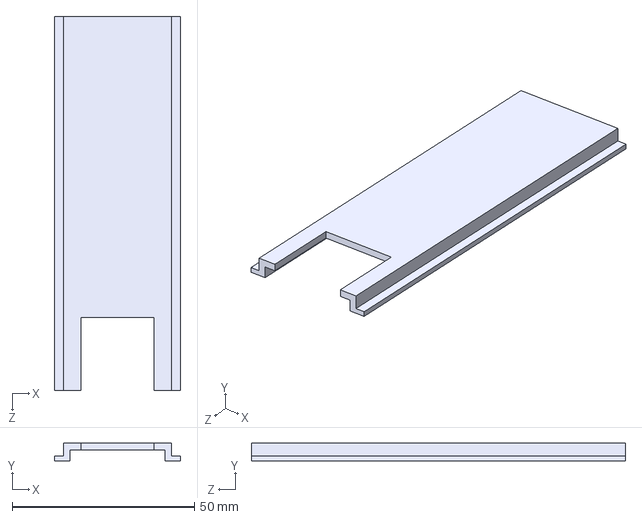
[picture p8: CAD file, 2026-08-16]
hardware/3d-models/solidworks建模/Blade上盖/宝剑上盖.STEP
34.6 x 4.80 x 102.5 mm

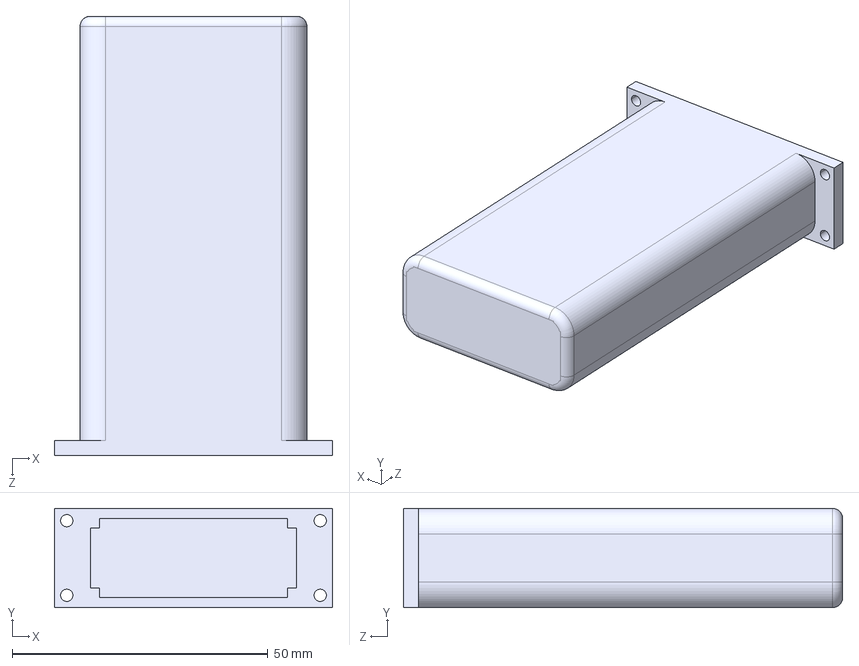
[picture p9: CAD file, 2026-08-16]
hardware/3d-models/solidworks建模/Blade剑柄/宝剑剑柄.STEP
54.4 x 19.4 x 86.0 mm

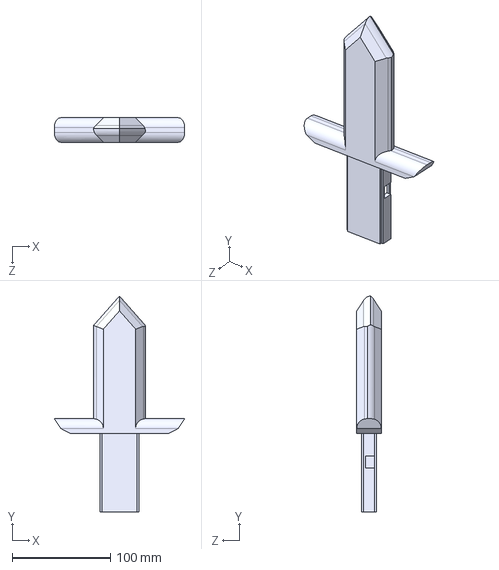
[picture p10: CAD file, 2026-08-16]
hardware/3d-models/solidworks建模/Blade剑身V1.0/宝剑（无心率检测模块）.STEP
132.9 x 220.0 x 25.0 mm

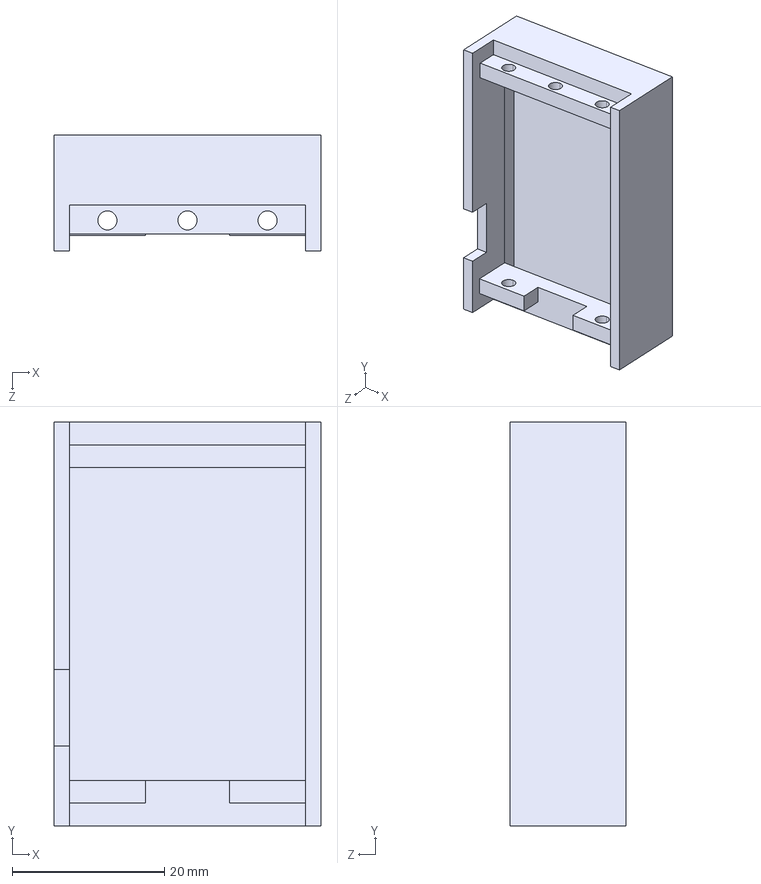
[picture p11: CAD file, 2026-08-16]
hardware/3d-models/solidworks建模/Tracker上半面V1.0/tracker上半面.STEP
35.0 x 53.0 x 15.2 mm

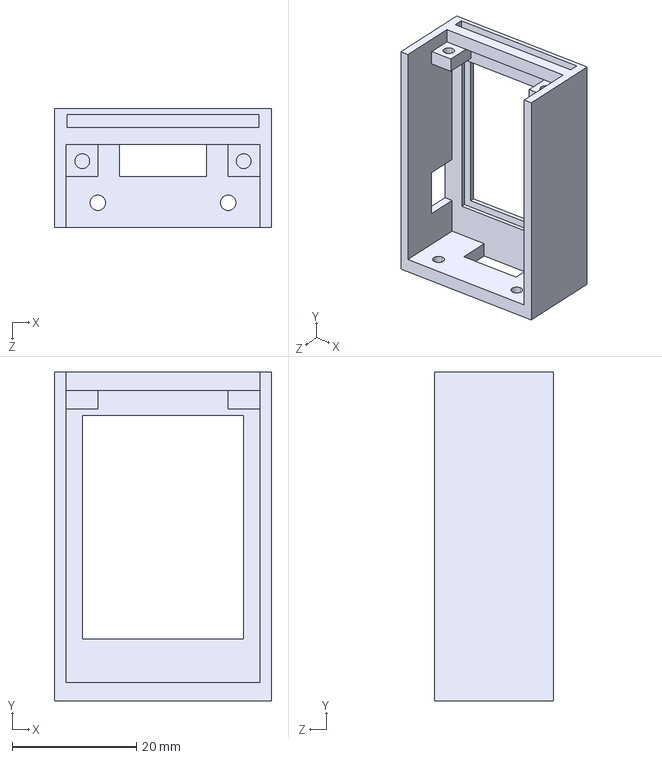
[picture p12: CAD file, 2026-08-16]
hardware/3d-models/solidworks建模/Tracker上半面V2.0（电池下置亚克力版本）/tracker上半面亚克力版.STEP
35.0 x 53.0 x 19.2 mm

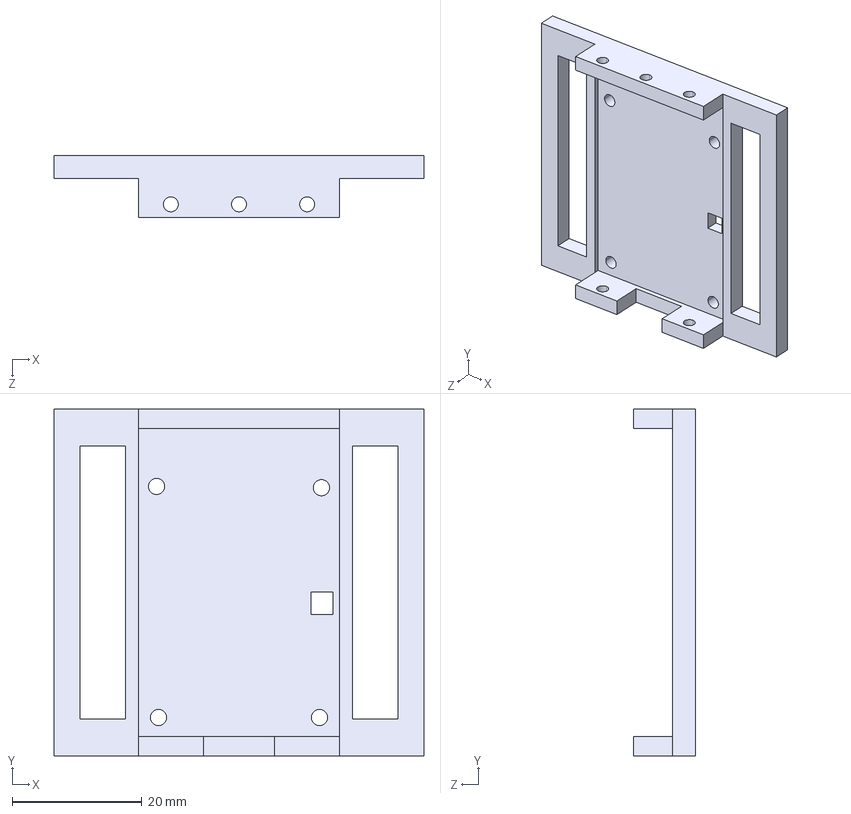
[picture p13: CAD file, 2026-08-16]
hardware/3d-models/solidworks建模/Tracker下半面V1.0/tracker下半面.STEP
57.0 x 53.4 x 9.50 mm

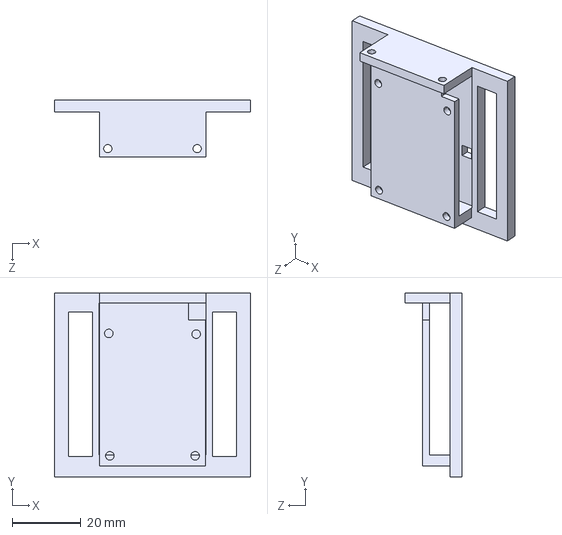
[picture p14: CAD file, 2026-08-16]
hardware/3d-models/solidworks建模/Tracker下半面V2.0（电池下置亚克力版）/tracker下半面亚克力透明版.STEP
57.0 x 53.4 x 16.7 mm

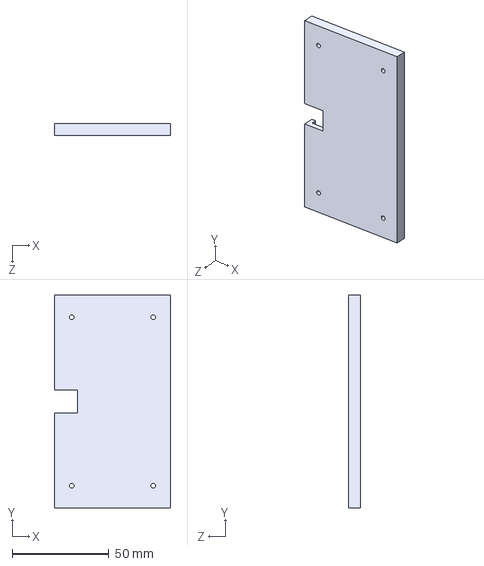
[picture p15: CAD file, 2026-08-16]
hardware/3d-models/solidworks建模/充电底座/充电底座.STEP
60.0 x 110.0 x 6.00 mm

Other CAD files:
hardware/3d-models/solidworks建模/Blade剑身V2.0（心率检测）/宝剑.STEP
hardware/3d-models/solidworks建模/Tracker下半面V2.0（电池下置亚克力版）/tracker下半面亚克力版.STL
hardware/3d-models/solidworks建模/Blade上盖/宝剑上盖.SLDPRT
hardware/3d-models/solidworks建模/Blade上盖/宝剑上盖.STL
hardware/3d-models/solidworks建模/Blade剑柄/宝剑剑柄.SLDPRT
hardware/3d-models/solidworks建模/Blade剑柄/宝剑剑柄.STL
hardware/3d-models/solidworks建模/Blade剑身V1.0/宝剑（无心率检测模块）.SLDPRT
hardware/3d-models/solidworks建模/Blade剑身V1.0/宝剑（无心率检测模块）.STL
hardware/3d-models/solidworks建模/Blade剑身V2.0（心率检测）/宝剑.SLDPRT
hardware/3d-models/solidworks建模/Blade剑身V2.0（心率检测）/宝剑.STL
hardware/3d-models/solidworks建模/Tracker上半面V1.0/tracker上半面.SLDPRT
hardware/3d-models/solidworks建模/Tracker上半面V1.0/tracker上半面.STL
hardware/3d-models/solidworks建模/Tracker上半面V2.0（电池下置亚克力版本）/tracker上半面亚克力版.SLDPRT
hardware/3d-models/solidworks建模/Tracker上半面V2.0（电池下置亚克力版本）/tracker上半面亚克力版.STL
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

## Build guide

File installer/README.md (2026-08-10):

# MoveToPlay Companion 队友安装包

运行 `build-team-installer.ps1` 会生成 win-x64 自包含发布版、注入本机外部保存的团队凭据、执行真实云端冒烟测试，再调用 Inno Setup 生成安装程序。私钥、API Token、引导凭据与最终安装包都位于 Git 忽略的本机目录或 `output/`，不会提交到仓库。

首次运行安装版时，`team-cloud.bootstrap.json` 会迁移到当前 Windows 用户的 DPAPI 加密文件并从安装目录删除。服务端对应公钥必须使用以下 `authorized_keys` 限制，只允许转发到回环地址的训练 API：

```text
restrict,port-forwarding,permitopen="127.0.0.1:8000",command="/bin/false"
```

构建命令：

```powershell
pwsh -File installer\build-team-installer.ps1
```

最终文件：

```text
output\installer\MoveToPlay.Companion.Team.Setup.exe
```

这是队友内部版本。安装包内的引导凭据可以被有意拆包的人读取；密钥已限制为 API 端口转发，但安装包仍不应公开发布。公开发行前应切换为 HTTPS 和独立用户令牌。

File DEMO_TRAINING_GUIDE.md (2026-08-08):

# MoveToPlay 决赛训练闭环操作说明

更新时间：2026-08-08

## 已经准备好的部分

- Windows Companion 可完成采集标注、SSH 连接、可续传上传、任务等待、指标展示、产物下载和人工批准。
- 阿里云 API 只监听 `127.0.0.1:8000`，电脑端通过 SSH 隧道访问，不需要域名和备案。
- Dongle 已合并为一份三态固件，不再保留独立 Data Collect 固件。
- 本机已缓存训练 Job `9968a258eb204188b18682471f30a4d8` 的清单和关键模型 C 文件，断网时仍能显示真实指标。
- 云端已有完整双随机森林训练结果，但保持未批准，人工批准必须由演示者确认指标后点击。

## 一、烧录统一 Dongle 固件

先连接 Dongle，确认设备管理器中的 COM 口，然后在 ESP-IDF PowerShell 环境执行：

```powershell
idf.py -B build-dongle-runtime -p COMx flash monitor
```

这同一份固件包含三种运行状态。每次长按 GPIO4 两秒循环切换：

```text
绿灯 Play → 橙灯 Data Collect → 蓝灯 Wi-Fi Maintenance → 重启回绿灯 Play
```

Play 到采集态不会重新枚举 USB，也不需要重新烧录。进入采集态时固件先释放全部键鼠，再停止推理/HID并从原 CDC 串口输出原始 CSV。

## 二、采集并标注

1. 启动 `MoveToPlay.Companion.exe`。
2. 点击主窗口左侧“数据采集与云端训练”。
3. 绿色 Play 下长按 Dongle 按钮两秒，确认指示灯变橙色。
4. 在“采集与标注”页刷新并选择 Dongle 原来的 CDC COM 口。
5. 打开四个 Tracker，确认“在线节点”逐步出现四个编号。
6. 选择连续状态标签，并在右侧预选本次事件动作；新增时点击“新建动作”，只填写显示名称，系统会自动生成内部编号。
7. 选择“即时标记”或推荐的“倒计时提示音”，点击“开始采集”。
8. 每按一次 Blade 只标记一次预选动作；倒计时方式应在听到提示音后开始动作，电脑按钮保留为备用。
9. 每种动作分多轮录制；动作前后各留约两秒，切换标签后先停一秒。
10. 点击“停止并保存”，软件会把本次会话加入“我的采集数据”。

即时方式默认向前补偿 50 ms，可在界面修改。Tracker 和 Blade 都使用 Dongle 接收时间对齐，因此 USB 排队不会直接变成动作标签偏移。

采集原始文件默认在：

```text
文档\MoveToPlay\collections\session-年月日-时分秒\
```

## 三、上传和训练

1. 切换到“我的采集数据”，勾选本次需要训练的一个或多个历史会话；需要时可定向删除自己的会话。
2. 点击“使用选中数据进入训练”，软件合并所选 CSV 后自动进入“云端训练”。
3. 点击“连接阿里云服务器”，状态应变为“阿里云已安全连接”。
4. 检查只读的 `samples.csv`、`events.csv` 和数据集名称，再点击“上传并开始训练”。服务器会把这些玩家会话叠加到固定官方数据集，不修改官方原始数据。
5. 等待状态依次变化：登记数据集、上传、入队、运行、通过。
6. 查看状态随机森林和事件随机森林的准确率、Macro F1、质量门禁。
7. 先点击“下载全部产物”留存一份，再决定是否“确认采用本次模型”。

上传中断后不要修改 CSV，重新点击会查询服务器接收偏移并继续。点击“停止等待”只停止电脑端轮询，不会删除服务器任务。也可以输入 32 位 Job ID 加载已经存在的任务。

## 四、模型进入固件

云端产物的 `generated/` 目录包含两个模型的 C 数组。批准只记录人工决策，不会悄悄改写 Dongle：

```text
generated/rf_state_model_generated.c
generated/rf_state_model_generated.h
generated/rf_model_generated.c
generated/rf_model_generated.h
```

Companion 会自动下载四个文件并核对服务器清单哈希，在 `%LOCALAPPDATA%\MoveToPlay\firmware\<Job ID>` 建立隔离工程，不改动当前源码的板型选择。点击“生成 Dongle 固件”后得到 bootloader、分区表、应用固件和 SHA-256 清单；再让 Dongle 进入蓝灯维护模式，手动选择其 COM 口并点击“烧录到 Dongle”。

生成和烧录前必须确认：

- 两个模型质量门禁通过；
- 类别顺序和特征数量符合固件；
- 下载文件哈希与 `run_manifest.json` 一致；
- 演示者已经点击人工批准；
- 烧录后在绿色 Play 状态做实机动作/HID 回归；新动作会按模型中的动作 ID 出现在 Wi-Fi 映射页，默认不输出按键，需由玩家配置。

## 五、现场兜底

- 首选比赛场地 Wi-Fi；不稳定时切到手机热点，SSH 不要求固定的电脑公网地址。
- 服务器不可达时，云端页会显示本机缓存的上次真实训练指标与关键 C 文件。
- 保留一份已经验证过的统一 Dongle 固件，不要在正式展示前只留下新训练但尚未回归的固件。
- 现场不要开放 ECS 的 8000 端口，也不要展示 API 令牌。

## 用户必须参与的最后验收

当前电脑没有识别到 Dongle，只看到系统/蓝牙串口，因此以下步骤必须在硬件接入后由用户配合：

1. 插入 Dongle，必要时按 BOOT/RESET 完成烧录。
2. 开启并佩戴四个 Tracker 与 Blade，执行真实动作。
3. 确认采集节点、动作标记时机和样本质量。
4. 查看最终指标并亲自决定是否批准。
5. 从橙灯再长按两秒进入蓝灯 Wi-Fi，再长按两秒重启回绿灯 Play，确认游戏键鼠行为符合预期。

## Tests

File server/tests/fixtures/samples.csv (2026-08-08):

pc_timestamp_ms | board_timestamp_ms | node_id | ax | ay | az | gx | gy | gz | state_label | session_id
1000 | 10 | 1 | 0.1 | 0.2 | 0.3 | 1 | 2 | 3 | idle | test_session
1001 | 11 | 2 | 0.1 | 0.2 | 0.3 | 1 | 2 | 3 | idle | test_session
1002 | 12 | 3 | 0.1 | 0.2 | 0.3 | 1 | 2 | 3 | idle | test_session
1003 | 13 | 4 | 0.1 | 0.2 | 0.3 | 1 | 2 | 3 | idle | test_session

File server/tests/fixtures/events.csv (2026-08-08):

event_id | event_group | event_type | pc_timestamp_ms | state_label | session_id
event-0001 | jump_event | jump | 1002 | idle | test_session

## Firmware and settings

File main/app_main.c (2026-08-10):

#include <stdbool.h>
#include <inttypes.h>
#include <stdint.h>
#include <stdio.h>
#include <stdlib.h>
#include <string.h>

#include "driver/gpio.h"
#include "driver/spi_master.h"
#include "esp_http_server.h"
#include "esp_log.h"
#include "esp_system.h"
#include "esp_timer.h"
#include "esp_adc/adc_oneshot.h"
#include "freertos/FreeRTOS.h"
#include "freertos/semphr.h"
#include "freertos/task.h"
#include "nvs.h"

#include "imu_lsm6dsv.h"
#include "max30102.h"
#include "m2p_espnow.h"
#include "rf_infer.h"
#include "rf_state_infer.h"
#include "usb_keyboard.h"
#include "battery_monitor.h"
#include "status_led.h"

static const char *TAG = "imu_main";

#define MOVE_TO_PLAY_MODE_DONGLE      0
#define MOVE_TO_PLAY_MODE_TRACKER     1
#define MOVE_TO_PLAY_MODE_BLADE       2

#define TRACKER_NODE_CHEST            1
#define TRACKER_NODE_RIGHT_HAND       2
#define TRACKER_NODE_LEFT_HAND        3
#define TRACKER_NODE_LEG              4

#define M2P_PROFILE_DONGLE            1
#define M2P_PROFILE_BLADE             2
#define M2P_PROFILE_TRACKER_CHEST     3
#define M2P_PROFILE_TRACKER_RIGHT_HAND 4
#define M2P_PROFILE_TRACKER_LEFT_HAND 5
#define M2P_PROFILE_TRACKER_LEG       6



/* Edit this value before clicking the VS Code ESP-IDF build/flash buttons.
 * M2P_BOARD_PROFILE: 1=dongle, 2=blade, 3=chest, 4=right_hand, 5=left_hand, 6=leg
 * *_BOARD_STYLE:     0=current, 1=new
 */
#define M2P_BOARD_PROFILE             1
#define M2P_CHEST_BOARD_STYLE         1
#define M2P_RIGHT_HAND_BOARD_STYLE    1
#define M2P_LEFT_HAND_BOARD_STYLE     1
#define M2P_LEG_BOARD_STYLE           1


#if M2P_BOARD_PROFILE == M2P_PROFILE_DONGLE
#define MOVE_TO_PLAY_DEVICE_MODE      MOVE_TO_PLAY_MODE_DONGLE
#define MOVE_TO_PLAY_TRACKER_NODE_ID  TRACKER_NODE_CHEST
#define MOVE_TO_PLAY_TRACKER_BOARD_STYLE M2P_CHEST_BOARD_STYLE
#elif M2P_BOARD_PROFILE == M2P_PROFILE_BLADE
#define MOVE_TO_PLAY_DEVICE_MODE      MOVE_TO_PLAY_MODE_BLADE
#define MOVE_TO_PLAY_TRACKER_NODE_ID  TRACKER_NODE_CHEST
#define MOVE_TO_PLAY_TRACKER_BOARD_STYLE M2P_CHEST_BOARD_STYLE
#elif M2P_BOARD_PROFILE == M2P_PROFILE_TRACKER_CHEST
#define MOVE_TO_PLAY_DEVICE_MODE      MOVE_TO_PLAY_MODE_TRACKER
#define MOVE_TO_PLAY_TRACKER_NODE_ID  TRACKER_NODE_CHEST
#define MOVE_TO_PLAY_TRACKER_BOARD_STYLE M2P_CHEST_BOARD_STYLE
#elif M2P_BOARD_PROFILE == M2P_PROFILE_TRACKER_RIGHT_HAND
#define MOVE_TO_PLAY_DEVICE_MODE      MOVE_TO_PLAY_MODE_TRACKER
#define MOVE_TO_PLAY_TRACKER_NODE_ID  TRACKER_NODE_RIGHT_HAND
#define MOVE_TO_PLAY_TRACKER_BOARD_STYLE M2P_RIGHT_HAND_BOARD_STYLE
#elif M2P_BOARD_PROFILE == M2P_PROFILE_TRACKER_LEFT_HAND
#define MOVE_TO_PLAY_DEVICE_MODE      MOVE_TO_PLAY_MODE_TRACKER
#define MOVE_TO_PLAY_TRACKER_NODE_ID  TRACKER_NODE_LEFT_HAND
#define MOVE_TO_PLAY_TRACKER_BOARD_STYLE M2P_LEFT_HAND_BOARD_STYLE
#elif M2P_BOARD_PROFILE == M2P_PROFILE_TRACKER_LEG
#define MOVE_TO_PLAY_DEVICE_MODE      MOVE_TO_PLAY_MODE_TRACKER
#define MOVE_TO_PLAY_TRACKER_NODE_ID  TRACKER_NODE_LEG
#define MOVE_TO_PLAY_TRACKER_BOARD_STYLE M2P_LEG_BOARD_STYLE
#else
#error "M2P_BOARD_PROFILE must be 1(dongle), 2(blade), 3(chest), 4(right_hand), 5(left_hand), or 6(leg)"
#endif

#define BOARD_NODE_ID                 MOVE_TO_PLAY_TRACKER_NODE_ID

#define MOVE_TO_PLAY_ENABLE_ESPNOW        1
#define MOVE_TO_PLAY_ESPNOW_SEND_SAMPLES  1

/* The Dongle always builds one unified firmware. Play, data collection and
 * Wi-Fi maintenance are runtime states selected with the GPIO4 button. */
#define DONGLE_ENABLE_SERIAL_OUTPUT       1
#define DONGLE_ENABLE_RF_INFERENCE        1
#define DONGLE_USE_CNN_INFER              0
#define DONGLE_ENABLE_HID_ACTION_LOG      1
#define DONGLE_ENABLE_ACTION_DEBUG_OUTPUT 0
#define DONGLE_ENABLE_HID_EVENT_LOG       0
#define DONGLE_ENABLE_USB_KEYBOARD        1
#define DONGLE_ENABLE_USB_MOUSE           1
#define DONGLE_ENABLE_USB_TELEMETRY        1
#define DONGLE_ENABLE_USB_KEYBOARD_TEST   0
#define DONGLE_ENABLE_USB_MOUSE_TEST      0

#include "move_to_play_board_config.h"

#define IMU_SPI_HOST                  SPI2_HOST
#define IMU_SPI_CLK_HZ                1000000
#define IMU_SAMPLE_RATE_HZ            100
#define IMU_SAMPLE_PERIOD_MS          (1000 / IMU_SAMPLE_RATE_HZ)
#define IMU_PRINT_DECIMATION          10
#define DONGLE_SERIAL_STATE_RATE_HZ   25
#define DONGLE_SERIAL_STATE_PERIOD_MS (1000 / DONGLE_SERIAL_STATE_RATE_HZ)
#define DONGLE_TELEMETRY_PERIOD_MS    100
#define DONGLE_TELEMETRY_STALE_MS     750
#define DONGLE_MAX_TRACKER_NODES      8
#define DONGLE_WIFI_DISPLAY_GPIO      GPIO_NUM_4
#define DONGLE_WIFI_DISPLAY_ACTIVE_LEVEL 0
#define DONGLE_MODE_SWITCH_HOLD_MS    2000
#define DONGLE_WIFI_DISPLAY_POLL_MS   50
#define DONGLE_WIFI_DISPLAY_AP_SSID   "MoveToPlay-Dongle"
#define DONGLE_WIFI_DISPLAY_AP_PASS   ""
#define DONGLE_WIFI_DISPLAY_AP_MAX_CONN 2
#define DONGLE_WIFI_DISPLAY_STATUS_UPDATE_MS 200
#define DONGLE_WIFI_DISPLAY_RX_DRAIN_DELAY_MS 5
#define DONGLE_PLAY_LED_R             0
#define DONGLE_PLAY_LED_G             20
#define DONGLE_PLAY_LED_B             0
#define DONGLE_COLLECT_LED_R          20
#define DONGLE_COLLECT_LED_G          8
#define DONGLE_COLLECT_LED_B          0
#define DONGLE_WIFI_LED_R             0
#define DONGLE_WIFI_LED_G             0
#define DONGLE_WIFI_LED_B             20
#define DONGLE_BLADE_MARKER_QUEUE_SIZE 8
#define DONGLE_STATUS_ONLINE_MAX_AGE_MS 1500
#define DONGLE_RF_MAX_NODE_AGE_MS     250
#define DONGLE_RF_PRINT_INTERVAL_MS   120
#define DONGLE_RF_MIN_CONFIDENCE      0.60f
#define DONGLE_BLADE_MAX_AGE_MS       300
#define DONGLE_BLADE_TURN_PERIOD_MS   20
#define DONGLE_BLADE_MOVE_RELEASE_GRACE_MS 220
#define DONGLE_BLADE_TURN_CHEST_NODE_ID TRACKER_NODE_CHEST
/* 0=gx, 1=gy, 2=gz. Current turn data shows chest gy has the strongest left/right yaw signal. */
#define DONGLE_BLADE_TURN_GYRO_AXIS   1
/* Mouse X is positive for turning right. With the current chest mounting, gy positive means left. */
#define DONGLE_BLADE_TURN_GYRO_SIGN   -1.0f
#define DONGLE_BLADE_TURN_DEADZONE_DPS 8.0f
#define DONGLE_BLADE_TURN_SENSITIVITY 10.0f /* mouse px per integrated gyro degree */
#define DONGLE_BLADE_TURN_MAX_STEP_DELTA 80
/* Chest gx is the shoulder-axis rotation used for looking up/down while Blade is held. */
#define DONGLE_BLADE_PITCH_GYRO_AXIS  0
/* USB mouse Y is positive downward. Flip this sign if the mounted chest tracker is inverted. */
#define DONGLE_BLADE_PITCH_GYRO_SIGN  1.0f
#define DONGLE_BLADE_PITCH_DEADZONE_DPS 8.0f
#define DONGLE_BLADE_PITCH_SENSITIVITY 8.0f /* lower than horizontal to reduce vertical jitter */
#define DONGLE_BLADE_PITCH_MAX_STEP_DELTA 64
#define DONGLE_BLADE_TURN_CHEST_MAX_AGE_MS 150

#define BLADE_NODE_ID                 100
#define BLADE_BUTTON_GPIO             GPIO_NUM_4
#define BLADE_POLL_RATE_HZ            50
#define BLADE_POLL_PERIOD_MS          (1000 / BLADE_POLL_RATE_HZ)
#define BLADE_REPORT_RATE_HZ          25
#define BLADE_REPORT_PERIOD_MS        (1000 / BLADE_REPORT_RATE_HZ)
#define BLADE_DEBOUNCE_SAMPLES        3
#define BLADE_ENABLE_SERIAL_OUTPUT    0
#define BLADE_SERIAL_STATE_RATE_HZ    10
#define BLADE_SERIAL_STATE_PERIOD_MS  (1000 / BLADE_SERIAL_STATE_RATE_HZ)

/* Heart-rate connector on the Blade: ESP32 side of the PCA9306 is 3.3 V. */
#define BLADE_HEART_RATE_SDA_GPIO     GPIO_NUM_6
#define BLADE_HEART_RATE_SCL_GPIO     GPIO_NUM_5
#define BLADE_HEART_RATE_INT_GPIO     GPIO_NUM_7
#define BLADE_HEART_RATE_POLL_MS      20
#define BLADE_HEART_RATE_SERIAL_MS    1000
#define BLADE_HEART_RATE_FINGER_MIN_IR 10000U
#define BLADE_HEART_RATE_DEFAULT_MEASUREMENT_SECONDS 10U
#define BLADE_HEART_RATE_FINGER_TIMEOUT_SECONDS 20U

#define BATTERY_REPORT_INTERVAL_MS    5000

#define ERROR_BLINK_PAUSE_MS          1500
#define TRACKER_LED_HEARTBEAT_PERIOD_MS 2000
#define TRACKER_LED_HEARTBEAT_ON_MS      120

#define USB_KEYBOARD_TEST_READY_TIMEOUT_MS 15000
#define USB_KEYBOARD_TEST_START_DELAY_MS   8000
#define USB_KEYBOARD_TEST_HOLD_MS          80
#define USB_MOUSE_TEST_START_OFFSET_MS     250
#define USB_MOUSE_TEST_LEFT_DELTA          80
#define USB_MOUSE_TEST_RIGHT_DELTA         48
#define USB_MOUSE_TEST_UP_DELTA            48
#define USB_MOUSE_TEST_DOWN_DELTA          48
#define USB_MOUSE_TEST_STEP_MS            120

#if (MOVE_TO_PLAY_DEVICE_MODE != MOVE_TO_PLAY_MODE_DONGLE) && \
    (MOVE_TO_PLAY_DEVICE_MODE != MOVE_TO_PLAY_MODE_TRACKER) && \
    (MOVE_TO_PLAY_DEVICE_MODE != MOVE_TO_PLAY_MODE_BLADE)
#error "MOVE_TO_PLAY_DEVICE_MODE must be 0 (dongle), 1 (tracker), or 2 (blade)"
#endif

#if DONGLE_ENABLE_USB_KEYBOARD_TEST && !DONGLE_ENABLE_USB_KEYBOARD
#error "DONGLE_ENABLE_USB_KEYBOARD_TEST requires DONGLE_ENABLE_USB_KEYBOARD"
#endif

#if DONGLE_ENABLE_USB_MOUSE_TEST && !DONGLE_ENABLE_USB_MOUSE
#error "DONGLE_ENABLE_USB_MOUSE_TEST requires DONGLE_ENABLE_USB_MOUSE"
#endif

#if DONGLE_SERIAL_STATE_RATE_HZ <= 0
#error "DONGLE_SERIAL_STATE_RATE_HZ must be greater than 0"
#endif

#if BLADE_ENABLE_SERIAL_OUTPUT && BLADE_SERIAL_STATE_RATE_HZ <= 0
#error "BLADE_SERIAL_STATE_RATE_HZ must be greater than 0"
#endif

#if BLADE_POLL_RATE_HZ <= 0
#error "BLADE_POLL_RATE_HZ must be greater than 0"
#endif

#if BLADE_REPORT_RATE_HZ <= 0
#error "BLADE_REPORT_RATE_HZ must be greater than 0"
#endif

#if (MOVE_TO_PLAY_TRACKER_NODE_ID < 1) || (MOVE_TO_PLAY_TRACKER_NODE_ID > DONGLE_MAX_TRACKER_NODES)
#error "MOVE_TO_PLAY_TRACKER_NODE_ID must be in range 1..DONGLE_MAX_TRACKER_NODES"
#endif

/* 预留后续按键/串口命令控制，第一版默认开启采样 */
static bool sampling_enabled = true;
static volatile bool s_local_battery_valid = false;
static volatile uint8_t s_local_battery_percent = M2P_ESPNOW_BATTERY_PERCENT_UNKNOWN;
static volatile uint16_t s_local_battery_mv = 0;
static portMUX_TYPE s_blade_heart_rate_mux = portMUX_INITIALIZER_UNLOCKED;
static uint16_t s_blade_heart_rate_bpm_x10 = 0;
static bool s_blade_heart_rate_valid = false;
static bool s_blade_finger_present = false;
static m2p_heart_rate_state_t s_blade_heart_rate_measurement_state = M2P_HEART_RATE_STATE_OFF;
static uint8_t s_blade_heart_rate_remaining_seconds = 0;
static uint32_t s_blade_heart_rate_command_generation = 0;
static bool s_blade_heart_rate_command_start = false;
static uint8_t s_blade_heart_rate_command_duration_seconds =
    BLADE_HEART_RATE_DEFAULT_MEASUREMENT_SECONDS;

static uint16_t battery_voltage_to_mv(float voltage)
{
    if (voltage <= 0.0f) {
        return 0;
    }

    const float mv = voltage * 1000.0f;
    if (mv >= 65535.0f) {
        return 65535U;
    }

    return (uint16_t)(mv + 0.5f);
}

static const char *tracker_node_name(uint8_t node_id)
{
    switch (node_id) {
    case TRACKER_NODE_CHEST:
        return "chest";
    case TRACKER_NODE_RIGHT_HAND:
        return "right_hand";
    case TRACKER_NODE_LEFT_HAND:
        return "left_hand";
    case TRACKER_NODE_LEG:
        return "leg";
    default:
        return "custom";
    }
}

static void led_init(void)
{
    status_led_init(STATUS_LED_SK6812_GPIO);
}

static inline void led_set(bool on)
{
    if (on) {
        status_led_set_color(10, 10, 10);
    } else {
        status_led_off();
    }
}

static void led_blink_startup(uint32_t times, uint32_t on_ms, uint32_t off_ms)
{
    for (uint32_t i = 0; i < times; i++) {
        led_set(true);
        vTaskDelay(pdMS_TO_TICKS(on_ms));
        led_set(false);
        vTaskDelay(pdMS_TO_TICKS(off_ms));
    }
}

static void imu_ctrl_pins_init(void)
{
    /* SPI 片选空闲为高；后续由 SPI 驱动接管 CS 翻转。 */
    gpio_reset_pin(IMU_SPI_CS_GPIO);
    gpio_set_direction(IMU_SPI_CS_GPIO, GPIO_MODE_OUTPUT);
    gpio_set_level(IMU_SPI_CS_GPIO, 1);
}

static esp_err_t spi_master_init(void)
{
    spi_bus_config_t bus_cfg = {
        .mosi_io_num = IMU_SPI_MOSI_GPIO,
        .miso_io_num = IMU_SPI_MISO_GPIO,
        .sclk_io_num = IMU_SPI_SCLK_GPIO,
        .quadwp_io_num = -1,
        .quadhd_io_num = -1,
        .max_transfer_sz = 16,
    };

    return spi_bus_initialize(IMU_SPI_HOST, &bus_cfg, SPI_DMA_CH_AUTO);
}

static void imu_error_loop(void)
{
    ESP_LOGE(TAG, "IMU init failed. Check wiring/power and SPI pins.");
    ESP_LOGE(TAG, "SPI pins: SCLK=%d MOSI=%d MISO=%d CS=%d",
             IMU_SPI_SCLK_GPIO,
             IMU_SPI_MOSI_GPIO,
             IMU_SPI_MISO_GPIO,
             IMU_SPI_CS_GPIO);

    while (1) {
        /* 快闪三次 + 间隔，便于肉眼识别错误状态 */
        for (int i = 0; i < 3; i++) {
            led_set(true);
            vTaskDelay(pdMS_TO_TICKS(80));
            led_set(false);
            vTaskDelay(pdMS_TO_TICKS(80));
        }
        vTaskDelay(pdMS_TO_TICKS(ERROR_BLINK_PAUSE_MS));
    }
}

static void imu_sampling_task(void *arg)
{
    (void)arg;

    TickType_t last_wake = xTaskGetTickCount();
    uint32_t sample_index = 0;
    uint32_t led_heartbeat_ms = 0;

    while (1) {
        imu_sample_t sample = {0};
        bool data_valid = false;

        if (sampling_enabled) {
            if (imu_lsm6dsv_read_sample(&sample) == ESP_OK) {
                data_valid = true;
            }
        }

        if (data_valid) {
#if MOVE_TO_PLAY_ENABLE_ESPNOW && MOVE_TO_PLAY_ESPNOW_SEND_SAMPLES
            esp_err_t send_err = m2p_espnow_send_tracker_sample(BOARD_NODE_ID,
                                                                sample_index,
                                                                &sample,
                                                                s_local_battery_valid,
                                                                s_local_battery_percent,
                                                                s_local_battery_mv);
            if (send_err != ESP_OK && (sample_index % IMU_SAMPLE_RATE_HZ) == 0) {
                ESP_LOGW(TAG, "ESP-NOW send failed: %s", esp_err_to_name(send_err));
            }
#endif

            if ((sample_index % IMU_PRINT_DECIMATION) == 0) {
                /* Tracker serial output: battery only (via battery_monitor_task) */
            }
            sample_index++;
        }

        /* Tracker heartbeat: briefly turn off LED to indicate alive, battery color is set by battery_monitor_task */
        if (led_heartbeat_ms < TRACKER_LED_HEARTBEAT_ON_MS) {
            status_led_off();
        }
        led_heartbeat_ms += IMU_SAMPLE_PERIOD_MS;
        if (led_heartbeat_ms >= TRACKER_LED_HEARTBEAT_PERIOD_MS) {
            led_heartbeat_ms = 0;
        }

        vTaskDelayUntil(&last_wake, pdMS_TO_TICKS(IMU_SAMPLE_PERIOD_MS));
    }
}

#if MOVE_TO_PLAY_ENABLE_ESPNOW
#if DONGLE_ENABLE_SERIAL_OUTPUT
typedef struct {
    bool valid;
    bool dirty;
    bool battery_valid;
    uint8_t src_addr[6];
    int64_t last_rx_us;
    int64_t last_battery_rx_us;
    uint16_t battery_mv;
    uint8_t battery_percent;
    m2p_espnow_tracker_packet_t packet;
} dongle_latest_node_t;

typedef struct {
    bool valid;
    bool pressed;
    bool dirty;
    bool battery_valid;
    bool heart_rate_valid;
    bool finger_present;
    m2p_heart_rate_state_t heart_rate_state;
    uint8_t heart_rate_remaining_seconds;
    uint8_t src_addr[6];
    uint8_t node_id;
    uint32_t sequence;
    uint32_t timestamp_us;
    int64_t last_rx_us;
    int64_t last_battery_rx_us;
    uint16_t battery_mv;
    uint8_t battery_percent;
    uint16_t heart_rate_bpm_x10;
} dongle_blade_state_t;

typedef enum {
    DONGLE_RUNTIME_PLAY = 0,
    DONGLE_RUNTIME_COLLECT = 1,
    DONGLE_RUNTIME_WIFI = 2,
} dongle_runtime_mode_t;

typedef struct {
    int64_t dongle_timestamp_us;
    uint32_t blade_edge_timestamp_us;
    uint32_t blade_sequence;
} dongle_blade_marker_t;

static dongle_latest_node_t s_dongle_latest_nodes[DONGLE_MAX_TRACKER_NODES];
static dongle_blade_state_t s_dongle_blade_state;
static volatile dongle_runtime_mode_t s_dongle_runtime_mode = DONGLE_RUNTIME_PLAY;
static volatile bool s_dongle_collect_blade_armed = false;
static dongle_blade_marker_t s_dongle_blade_markers[DONGLE_BLADE_MARKER_QUEUE_SIZE];
static uint8_t s_dongle_blade_marker_head = 0;
static uint8_t s_dongle_blade_marker_count = 0;
static SemaphoreHandle_t s_dongle_state_mutex;
#if DONGLE_ENABLE_USB_KEYBOARD || DONGLE_ENABLE_USB_MOUSE
static SemaphoreHandle_t s_dongle_hid_mutex;
#endif
static int64_t s_dongle_display_last_tracker_store_us[DONGLE_MAX_TRACKER_NODES];
#if DONGLE_ENABLE_USB_MOUSE
static int64_t s_dongle_last_blade_turn_us = 0;
static float s_dongle_blade_turn_dx_remainder = 0.0f;
static float s_dongle_blade_turn_dy_remainder = 0.0f;
#endif
#if DONGLE_ENABLE_ACTION_DEBUG_OUTPUT
static int64_t s_dongle_last_rf_print_us = 0;
#endif

static dongle_latest_node_t *dongle_latest_node_for_id(uint8_t node_id)
{
    if (node_id == 0 || node_id > DONGLE_MAX_TRACKER_NODES) {
        return NULL;
    }

    return &s_dongle_latest_nodes[node_id - 1];
}

static void dongle_state_lock(void)
{
    if (s_dongle_state_mutex != NULL) {
        (void)xSemaphoreTake(s_dongle_state_mutex, portMAX_DELAY);
    }
}

static void dongle_state_unlock(void)
{
    if (s_dongle_state_mutex != NULL) {
        (void)xSemaphoreGive(s_dongle_state_mutex);
    }
}

static void dongle_store_latest_packet(const m2p_espnow_rx_packet_t *rx_packet)
{
    if (rx_packet->packet.type != M2P_ESPNOW_PACKET_TRACKER_IMU) {
        return;
    }

    const uint8_t node_id = rx_packet->packet.node_id;
    dongle_latest_node_t *node = dongle_latest_node_for_id(node_id);
    if (node == NULL) {
        return;
    }

    dongle_state_lock();

    if (!node->valid) {
        ESP_LOGI(TAG,
                 "tracker online: node_id=%u (%s)",
                 node_id,
                 tracker_node_name(node_id));
    }

    node->valid = true;
    node->dirty = true;
    node->last_rx_us = esp_timer_get_time();
    memcpy(node->src_addr, rx_packet->src_addr, sizeof(node->src_addr));
    node->packet = rx_packet->packet;
    if ((rx_packet->packet.flags & M2P_ESPNOW_TRACKER_FLAG_BATTERY_VALID) != 0 &&
        rx_packet->packet.battery_percent <= 100U) {
        node->battery_valid = true;
        node->battery_percent = rx_packet->packet.battery_percent;
        node->battery_mv = rx_packet->packet.battery_mv;
        node->last_battery_rx_us = node->last_rx_us;
    }

    dongle_state_unlock();
}

static bool dongle_wifi_display_should_store_tracker_packet(const m2p_espnow_rx_packet_t *rx_packet,
                                                            int64_t now_us)
{
    const uint8_t node_id = rx_packet->packet.node_id;
    if (node_id == 0 || node_id > DONGLE_MAX_TRACKER_NODES) {
        return false;
    }

    int64_t *last_store_us = &s_dongle_display_last_tracker_store_us[node_id - 1U];
    if (*last_store_us <= 0 ||
        (now_us - *last_store_us) >= ((int64_t)DONGLE_WIFI_DISPLAY_STATUS_UPDATE_MS * 1000LL)) {
        *last_store_us = now_us;
        return true;
    }

    return false;
}
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
void app_main(void)
{
    led_init();

    led_blink_startup(3, 120, 120);

    ESP_LOGI(TAG, "Booting MoveToPlay");
    ESP_LOGI(TAG, "device_mode=%d (0=dongle, 1=tracker, 2=blade)",
             MOVE_TO_PLAY_DEVICE_MODE);

    if (MOVE_TO_PLAY_DEVICE_MODE == MOVE_TO_PLAY_MODE_DONGLE) {
        start_dongle_mode();
    } else if (MOVE_TO_PLAY_DEVICE_MODE == MOVE_TO_PLAY_MODE_TRACKER) {
        xTaskCreatePinnedToCore(battery_monitor_task,
                                "battery_task",
                                3072,
                                NULL,
                                3,
                                NULL,
                                tskNO_AFFINITY);
        start_tracker_mode();
    } else {
        xTaskCreatePinnedToCore(battery_monitor_task,
                                "battery_task",
                                3072,
                                NULL,
                                3,
                                NULL,
                                tskNO_AFFINITY);
        start_blade_mode();
    }
}

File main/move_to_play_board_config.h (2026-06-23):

#pragma once

#include "driver/gpio.h"
#include "esp_adc/adc_oneshot.h"

#ifndef MOVE_TO_PLAY_TRACKER_BOARD_STYLE
#error "Define MOVE_TO_PLAY_TRACKER_BOARD_STYLE in app_main.c before including this file"
#endif

#define MOVE_TO_PLAY_TRACKER_BOARD_CURRENT 0
#define MOVE_TO_PLAY_TRACKER_BOARD_NEW     1

#if (MOVE_TO_PLAY_TRACKER_BOARD_STYLE != MOVE_TO_PLAY_TRACKER_BOARD_CURRENT) && \
    (MOVE_TO_PLAY_TRACKER_BOARD_STYLE != MOVE_TO_PLAY_TRACKER_BOARD_NEW)
#error "MOVE_TO_PLAY_TRACKER_BOARD_STYLE must be 0(current) or 1(new)"
#endif

#if MOVE_TO_PLAY_TRACKER_BOARD_STYLE == MOVE_TO_PLAY_TRACKER_BOARD_CURRENT
#define MOVE_TO_PLAY_TRACKER_BOARD_NAME "current"
#define IMU_SPI_SCLK_GPIO              GPIO_NUM_12
#define IMU_SPI_MOSI_GPIO              GPIO_NUM_11
#define IMU_SPI_MISO_GPIO              GPIO_NUM_9
#define IMU_SPI_CS_GPIO                GPIO_NUM_10
#define STATUS_LED_SK6812_GPIO         GPIO_NUM_38
#define BATTERY_ADC_GPIO               GPIO_NUM_4
#define BATTERY_ADC_UNIT               ADC_UNIT_1
#define BATTERY_ADC_CHANNEL            ADC_CHANNEL_3
#else
#define MOVE_TO_PLAY_TRACKER_BOARD_NAME "new"
#define IMU_SPI_SCLK_GPIO              GPIO_NUM_13
#define IMU_SPI_MOSI_GPIO              GPIO_NUM_12
#define IMU_SPI_MISO_GPIO              GPIO_NUM_11
#define IMU_SPI_CS_GPIO                GPIO_NUM_14
#define STATUS_LED_SK6812_GPIO         GPIO_NUM_38
#define BATTERY_ADC_GPIO               GPIO_NUM_2
#define BATTERY_ADC_UNIT               ADC_UNIT_1
#define BATTERY_ADC_CHANNEL            ADC_CHANNEL_1
#endif

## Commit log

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2026-04-15 修正了REG_OUTX_L_G/A寄存器地址
2026-04-15 增添了两个板子之间的通信模块
    设置了dongle和tracker的模式切换，以及键盘模式是否开启切换（方便调试，因为开启键盘模式电脑就烧录不了代码了，需要手动复位）以下为设置切换的位置
    #define MOVE_TO_PLAY_DEVICE_MODE MOVE_TO_PLAY_MODE_TRACKER
    #define MOVE_TO_PLAY_ENABLE_ESPNOW 1
    #define MOVE_TO_PLAY_ESPNOW_SEND_SAMPLES 1
    #define DONGLE_ENABLE_SERIAL_OUTPUT 1
    #define DONGLE_ENABLE_USB_KEYBOARD 0
    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
2026-04-16 把引脚改成了最新的板子，修改了 REG_OUTX_L_G/A，AI让改的
    AI说之前的数据不对是写反了，又改回来了。
    同时显式设置修改了：
    #define CTRL6_C_1000DPS 0x03
    #define CTRL8_XL_4G 0x01
    这对应陀螺仪 ±1000dps、加速度 ±4g，和当前换算系数匹配。
2026-04-17 修改了一下灯光闪烁逻辑，之前的闪太快了
    启动闪 3 次：程序开始运行
    dongle 常亮：进入 dongle 模式
    tracker 先亮 0.5 秒：IMU 初始化成功
    tracker 每 2 秒短亮一下：正常采样运行中
    三连快闪反复：IMU/SPI 初始化失败
2026-04-17 fix(imu): 修正 LSM6DSV gyro 初始化配置并增加双路 ready 同步检查
    根因修复：此前并非 STATUS_REG 判读错误，而是 LSM6DSV 的 gyro 初始化寄存器语义使用错误。
    在 ST 官方 lsm6dsv-pid 语义下：
    - CTRL1_XL(0x10) / CTRL2_G(0x11) 仅配置 ODR 与 op_mode
    - FS_G 应配置在 CTRL6_C(0x15)
    - FS_XL 应配置在 CTRL8_XL(0x17)
    原先将 CTRL2_G 设为 0x48，会被芯片解释为：
    - odr_g = 0x8（480 Hz）
    - op_mode_g = 0x4（GY_SLEEP_MD）
    这会导致 accel 正常输出、gyro 长时间处于 sleep 路径，因此反复出现 STATUS_REG=0x05（XLDA=1, GDA=0）。
    本次修改内容：
    1. 修正 LSM6DSV 初始化配置语义
    - 将 CTRL1_XL / CTR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
    [imu_lsm6dsv.c]
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2026-04-17 feat: 新增电脑端 IMU 姿态融合与可视化验证脚本
    主要功能：
    - 从串口读取 dongle 转发的 IMU 数据
    - 解析 seq、加速度和角速度
    - 启动时静止 3 秒估计陀螺仪零偏
    - 用 6 轴 Mahony 融合输出四元数和欧拉角
    - 终端实时显示姿态和 motion flag
    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
2026-04-17 feat(pc): 增加双节点 IMU 最小闭环验证
    实现第五阶段轻量 Python 验证程序，遵循“四元数优先、节点状态隔离”的原则，完成 chest+hand 最小闭环。
    本次实现：
    - 新增双节点会话，固定角色映射：node=1(chest)、node=2(hand)
    - 串口混合行鲁棒解析，自动跳过空行/日志/非法行
    - 每个节点独立融合状态，严禁共用融合器
    - 基于 6 轴 Mahony（acc+gyro，无磁力计）分别融合 chest/hand
    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
2026-04-19 feat(imu): 增加零偏校准和稳定 dt 计算
    改动1：零点校准：
    - 增加 b 键和自动模式，用于静止陀螺仪零偏校准
    - 每个节点独立保存 gyro bias，并在 Mahony 融合前扣除
    - 零偏校准完成后重置姿态状态
    改动2：更稳定的dit：
    为什么更稳定的dit?
    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
2026-04-19 feat(imu): 增加快速运动下的自适应加速度权重
    优化快速运动时的 IMU 姿态融合稳定性。
    因为快速运动时加速度计测到的不只是重力，还混入了甩动/冲击产生的加速度导致测量不准，所以有时需要降低它的权重，避免它把姿态角修正错。
    - 为 Mahony 融合增加加速度计修正权重
    - acc_norm 接近 1g 时完全信任加速度计
    - acc_norm 偏离 1g 时逐步降低加速度计修正
    - 快速运动或冲击时暂时忽略加速度计修正
    - 在监视输出中显示加速度权重 aw
    - 单节点和双节点 Python 工具使用相同逻辑
    [imu_dual_node_phase5.py, imu_fusion_monitor.py]
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2026-04-20 feat(dongle): 将串口输出统一为纯数字 IMU CSV 格式
    - 将 dongle 串口输出从 key=value 日志格式改为纯数字 CSV
    - 统一输出为 timestamp_ms,node_id,ax,ay,az,gx,gy,gz
    - 去掉 seq、src、age_ms 等采集阶段不需要的调试字段
    - 便于上位机稳定采集和后续训练数据落盘
2026-04-20 refactor(tools): 让单节点融合监视器适配新的 CSV 数据流
    - 单节点串口解析改为 8 列纯数字 CSV
    - 在日志中补充 node_id 和 board_timestamp_ms
    - 优先使用 board timestamp 估算 dt
    - 保持现有姿态融合和监视输出逻辑不变
2026-04-20 feat(tools): 新增 IMU 数据采集与实时标签脚本
    - 新增命令行 IMU 采集脚本 collect_imu_data.py
    - 支持串口实时读取、键盘切标签、暂停/继续、分 session 保存
    - 输出训练友好的 CSV 字段：时间戳、node_id、6 轴原始数据、label、
    session_id
    - 将 data/ 目录加入 .gitignore，避免采集数据误入版本库
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2026-04-20 feat(infer): 增加随机森林实时推理脚本
    - 新增 tools/rf_realtime_infer.py，用于从串口实时读
    取双节点 IMU 数据并执行随机森林动作推理
    - 推理输入格式为纯数字 CSV：
    timestamp_ms,node_id,ax,ay,az,gx,gy,gz
    - 实时推理流程与训练阶段保持一致：
    多节点时间对齐 -> 窗口构建 -> 特征提取 -> Random
    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
2026-04-21 feat(usb): 加上了键盘+鼠标复合 HID 功能
    - 基于 fork 最新代码，重新接入并整理 USB HID 输入模块
    - 保留原有键盘功能，同时增加鼠标相对移动、按键按下/释放、点击接口
    - 将 USB 设备改为键盘+鼠标复合 HID，支持后续体感逻辑按需交替发送键盘或鼠标输入
    - 补充鼠标相关宏定义与 API，便于后续将动作识别结果映射到鼠标控制
    - 增加键盘/鼠标测试任务与独立开关，方便单独验证 HID 功能
    - 为 HID 报告发送增加短时重试，降低键盘和鼠标测试同时发送时的丢包概率
    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
2026-04-23 feat(debug): 增强多节点联调配置并补充 dongle 数据年龄输出
    dongle的串口输出为
    timestamp_ms, node_id, ax, ay, az, gx, gy, gz, age_ms
    增加 dongle / tracker 模式切换注释，明确烧录前需要修改的位置
    增加 4 个预设节点编号，便于多节点测试：
    1 = chest
    2 = right_hand
    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
2026-04-27 feat(label): 抽取共享动作标签定义并让采集器复用
    - 新增 tools/action_labels.py，集中维护动作标签键位映射
    - 让 collect_imu_data.py 改为复用共享标签定义，避免采集和训练标签漂移
    - 采集器帮助输出改为根据共享标签表动态生成，减少后续重复修改
    - 补上 tools 目录脚本的项目根路径导入逻辑，避免直接运行时报 No module named '
2026-04-27 feat(ml): 将随机森林训练默认切换为完整多分类标签集
    - 将 rf_baseline.py 的默认任务从 three_class 改为 multiclass
    - 训练类别顺序改为复用采集器动作标签定义，保持采集/训练一致
    - 更新脚本说明文案，明确默认使用完整动作标签集
    - 补上项目根路径导入逻辑，支持直接运行训练脚本
2026-04-27 feat(infer): 提升实时推理对串口日志和扩展 CSV 的容错性
    - 让 rf_realtime_infer.py 自动跳过 ESP-IDF 启动日志和说明性文本
    - 兼容带 age_ms 的 9 列 dongle 串口输出，不再强制要求恰好 8 列
    - 将串口解析结果区分为有效数据、跳过行和 malformed 行，便于排查
    - 在实时状态输出中增加 skip 计数，方便观察日志噪声占比
    [rf_realtime_infer.py]
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2026-05-12 feat(dongle): 启用 USB HID 键鼠输出、SK6812 电量指示灯及动作触发控制逻辑
    - 开启 USB keyboard + mouse 输出（DONGLE_ENABLE_USB_KEYBOARD/MOUSE = 1）
    - 新增 battery_monitor 模块（ADC 电量检测与百分比输出）
    - 新增 status_led 模块（SK6812 RGB LED 根据电量显示颜色）
    - 实现推理结果到按键/鼠标的完整映射：
    walk->W, run->SHIFT+W, jump->SPACE, left_hand_raise->ESC,
    right_hand_raise->M, hands_chest_push->Q, hands_cross_chest->E,
    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
2026-05-14 feat: 1D CNN 推理引擎 + 动作采集工具链升级
    === 模型层 ===
    - 新增 1D CNN 训练脚本 (tools/cnn1d_train.py)，测试集准确率 99.68%
    - 新增 CNN 权重导出脚本 (tools/export_cnn1d_c.py)，融合 BatchNorm 后导出 C 数组
    - 新增板端 CNN 推理引擎 (main/cnn_infer.c/h)，手写 Conv1d+ReLU+AvgPool+Linear
    - 更新随机森林模型为 newmodel 版本（25956 节点）
    - app_main.c 支持 DONGLE_USE_CNN_INFER 开关切换 RF/CNN 推理后端
    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
2026-07-04 fix(blade): 转身接管时释放过期移动按键
    修复跑步中持续 Blade 转身后，停下再继续转身时可能仍保留 run/walk 按键保持的问题。
    问题路径是 RF 输出 turn_left/turn_right 时，Blade 会接管鼠标视角并提前返回；如果之前已经按住 W 或 Shift+W，而后续没有新的 walk/run 状态刷新，就可能没有机会释放旧的移动按键。
    新增 DONGLE_BLADE_MOVE_HOLD_GRACE_MS，Blade 接管视角时检查最近一次 state 刷新时间；如果当前保持的是 walk/run 且超过 300ms 未刷新，主动释放键盘保持。
    这样保留了边跑边转的叠加体验，但停止跑步后不会无限继承上一段 run/walk 状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
    [app_main.c]
2026-07-04 fix(blade): 简化转身时的移动保持逻辑
    移除 Blade 转身期间基于 300ms 的 walk/run 过期释放判断，避免正常走路转身时因为 RF 暂时输出 turn 类动作而主动释放 W 或 Shift+W。
    Blade 按下时仍然覆盖 RF 的 turn_left/turn_right 鼠标转向，防止 RF 转身和胸部 Tracker 转身叠加；但移动状态继续交给原来的 walk、run、idle 状态机处理。
    遵循 KISS 原则：Blade 只负责视角转向，不在 Blade 通道里额外猜测玩家是否已经停止移动。
    [app_main.c]
2026-07-06 Dongle 新增 Wi-Fi 显示模式，网页可以配置按键和触发方式，Tracker 电量上报dongle，Flash 配置统一为 8MB
    详细修改：
    - Dongle 新增 GPIO8 长按 4 秒进入 Wi-Fi display mode，启动 MoveToPlay-Dongle SoftAP，并提供 http://192.168.4.1/ 状态网页。
    - 网页状态页改为中文界面，显示 tracker 在线状态、电量、电压、最后数据时间，并新增 blade 在线状态、按键状态、最后数据时间和 sequence。
    - 新增网页按键配置表，可以配置每个识别动作的输出类型、按键、组合键、触发方式、置信度阈值、冷却时间和持续帧；配置保存到 dongle NVS，重启后继续生效，并支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
    [partitions.csv, partitions_16mb.csv, partitions_8mb.csv]
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2026-07-06 fix(blade): 消除走路转身结束时的移动卡顿
    在 Blade 转身刚结束后的短时间内，如果模型短暂掉到 idle 或 move_noise，而当前键盘仍保持 walk/run，则继续保留原移动按键，避免 W 被释放后又重按造成走路顿一下。
    保护窗口设置为 220ms，只作用于 walk/run 这类移动保持动作，不影响攻击、跳跃、奥特曼光线、射击等触发类动作。
    同时修正鼠标 HID 路径的条件编译开关，把鼠标点击、移动、按住和释放相关调用从 DONGLE_ENABLE_USB_KEYBOARD 改为 DONGLE_ENABLE_USB_MOUSE，避免后续单独调整键鼠开关时埋隐患。
    验证：ninja 构建通过，esp_idf_template.bin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
    [app_main.c]
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2026-07-16 feat(dongle): 移动类不对称触发, 降低起步延迟
    - walk/run 入场置信度 0.60→0.52, 确认帧独立为 4 帧 (其余动作不变)
    - 入场与维持阈值统一, 修复边缘置信度导致的 W 键抖动
    - 转身灵敏度 6.0→10.0, 补偿实际转角与画面转角差距
    [app_main.c]
2026-07-16 chore(analysis): 新增跳跃识别诊断脚本
    - diagnose_jump_context: 按前置状态(idle/walk/run)全流水线仿真
    jump 触发率, 已验证算法链路 123/123 全部触发, 排除算法问题
    - diagnose_jump_hands: 量化跳跃时手部运动分布, 96% 训练样本
    手部大幅摆动, 确认举手跳识别不到为数据覆盖问题
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2026-07-17 fix: 支持移动过程中组合键跳跃
    原跳跃逻辑会先释放 walk/run 的持续按键，再单独发送空格，导致移动中跳跃不稳定。
    现在根据跳跃前的移动状态发送组合 HID 报告：
    - walk: W + Space
    - run: Shift + W + Space
    空格脉冲结束后立即恢复 W 或 Shift+W，保持移动连续性。
    [app_main.c]
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2026-08-08 fix(dongle): 撤回 jump 特殊置信度,
    - jump 置信度恢复默认 0.60 (撤回 2607f1b 的 0.40)
    [app_main.c]
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2026-08-08 fix: 适配云服务器容器镜像网络
    将 Python 官方基础镜像切换到 ECS 已验证可访问的 ECR Public，并固定镜像摘要，避免 Docker Hub 超时和后续镜像漂移。
2026-08-08 fix: 使用阿里云镜像安装服务依赖
    为容器构建配置阿里云 PyPI 镜像、下载超时和重试次数，解决中国大陆 ECS 访问 Python 官方文件站不稳定的问题。
2026-08-08 fix: 固定云端镜像可用的接口依赖版本
    将 Starlette 固定为阿里云 PyPI 已同步且与 FastAPI 兼容的 1.4.1；本机接口测试全部通过。
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2026-08-08 fix: 收紧云端训练数据目录权限
    统一使用 0077 umask，将持久目录设为 0700、SQLite 状态库和新建数据文件设为 0600，避免同机其他用户读取训练元数据。
2026-08-08 test: 增加云端接口冒烟测试数据
    将四节点最小 processed CSV 固化为测试夹具，既供本机端到端测试，也可在部署后通过真实上传 API 验证 worker。
    [events.csv, samples.csv]
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2026-08-08 fix: 恢复在源码中选择烧录板型
    移除构建目录对 M2P_BOARD_PROFILE 的强制覆盖，重新允许在 app_main.c 中修改 1 至 6 后直接使用 VS Code ESP-IDF 编译和烧录按钮。同步更新构建说明与风险提示。
    [app_main.c]
2026-08-08 fix: 简化自定义动作与标记参数界面
    将新建动作和保存修改拆分，自动生成系统动作编号，并用中文动作类别替代事件组 ID 输入。明确列表移除不会删除历史标签、云端数据或模型；即时与倒计时模式只显示各自适用的时间参数。
2026-08-08 fix: 移除玩家侧动作分类选项
    新建动作只需填写显示名称，内部继续使用默认事件分组兼容训练 CSV；旧动作已有分组保持不变，不再让玩家处理无实际必要的分类字段。
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2026-08-09 修复采集串口交接并完善自动动作标注
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2026-08-09 修正历史训练进度并增强回滚保护
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2026-08-09 修正内置烧录器的固件地址排序
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2026-08-09 修正云端固件编译进度解析
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2026-08-10 修复游玩激励弹窗被连接状态覆盖
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2026-08-14 Add SolidWorks 3D model sources
    [tracker上半面亚克力版.SLDPRT, tracker下半面亚克力透明版.SLDPRT, 充电底座.SLDPRT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]
2026-08-16 整理 PCB 与 3D 模型复刻说明
    [tracker上半面.SLDPRT, tracker上半面.STEP, tracker上半面.STL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]
2026-08-16 开源随机森林训练数据与完整复现工具
    [event_events_combined_slash_full.csv, event_samples_combined_slash_full.csv]
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

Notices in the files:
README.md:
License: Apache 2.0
